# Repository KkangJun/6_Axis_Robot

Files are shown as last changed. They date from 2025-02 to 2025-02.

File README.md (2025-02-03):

Start : 2024. 12. 18
====================
v1.0 End : 2025. 02. 03
======================
   
## Introduction
 This project is a compilation of documents that I developed for my 6-axis manipulator robot.   
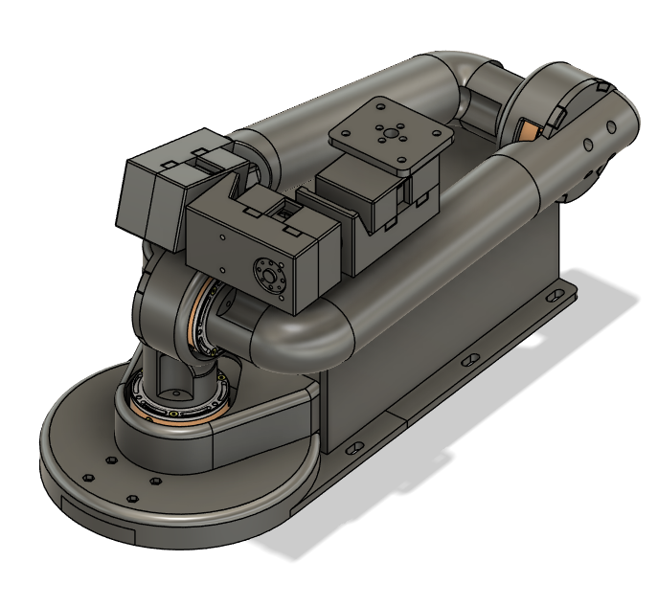
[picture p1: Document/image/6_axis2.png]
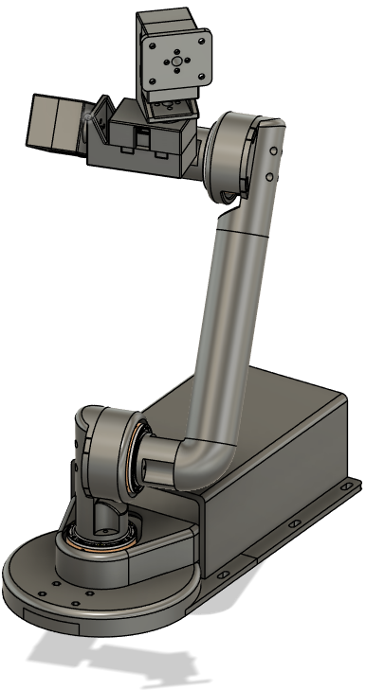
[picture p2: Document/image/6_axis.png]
<br/> <br/>
   
### Ver 1.0 Implement
 #### - Initialize -
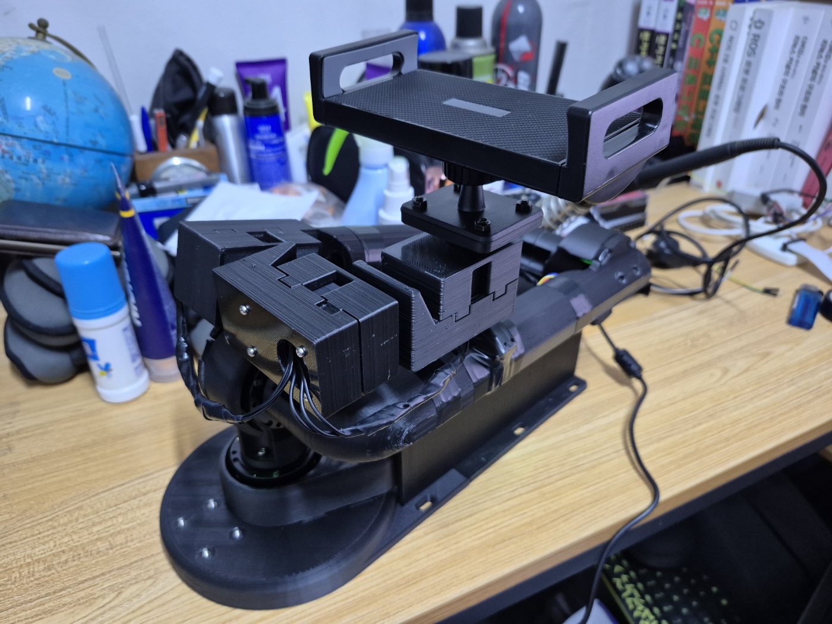
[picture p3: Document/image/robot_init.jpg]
<br/><br/>

 ##### The robot is initialized in the following cases:   
1. Power on the robot
2. Connect the App to the robot
3. Press the Reset button on the App
   
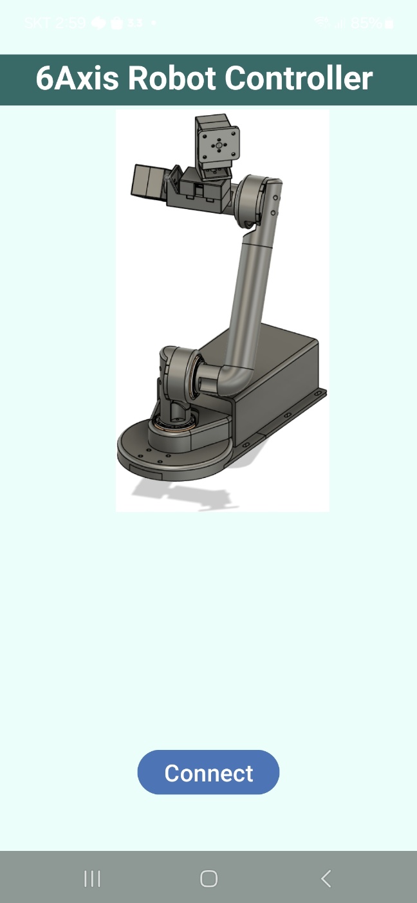
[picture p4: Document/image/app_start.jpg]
<br/><br/>
   
 #### - Motor control -
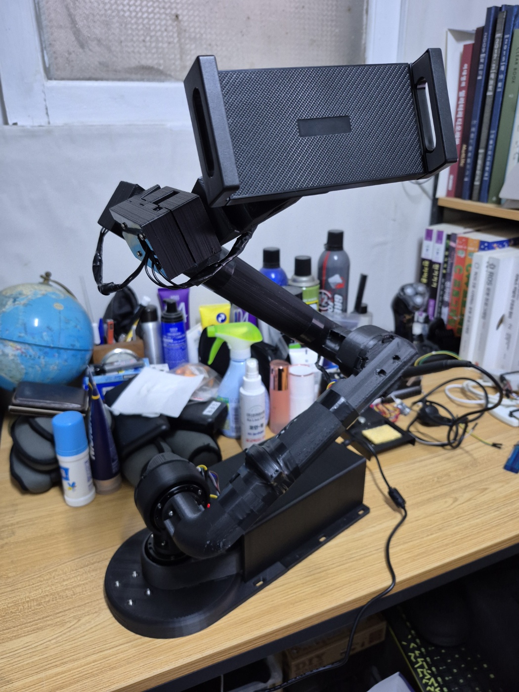
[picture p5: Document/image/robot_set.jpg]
<br/><br/>

 ##### To control each joint of the robot, we use the following methods:   
1. Set the motor angle by sliding or typing numbers
2. Press the RUN button to operate the motor according to the set angle value
3. Adjust the angle in the RUN state to operate the motor
   
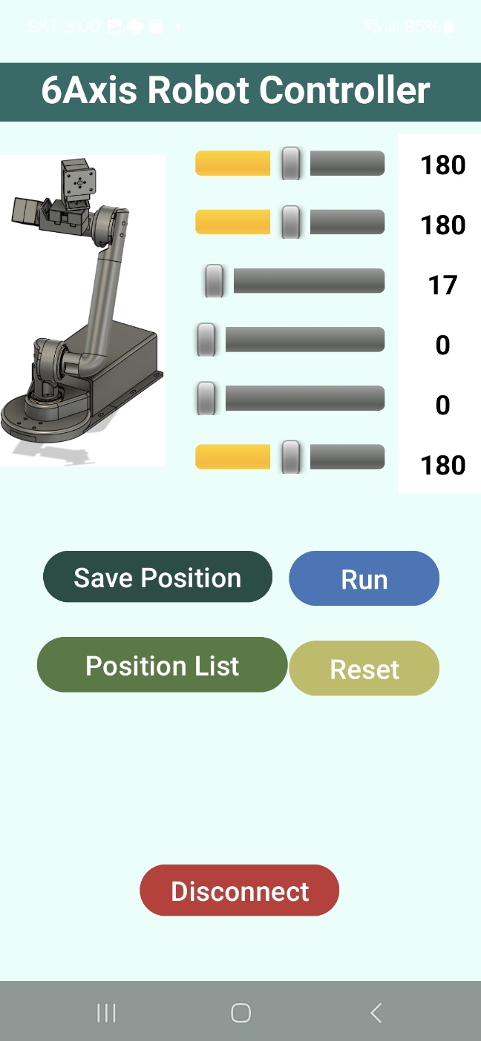
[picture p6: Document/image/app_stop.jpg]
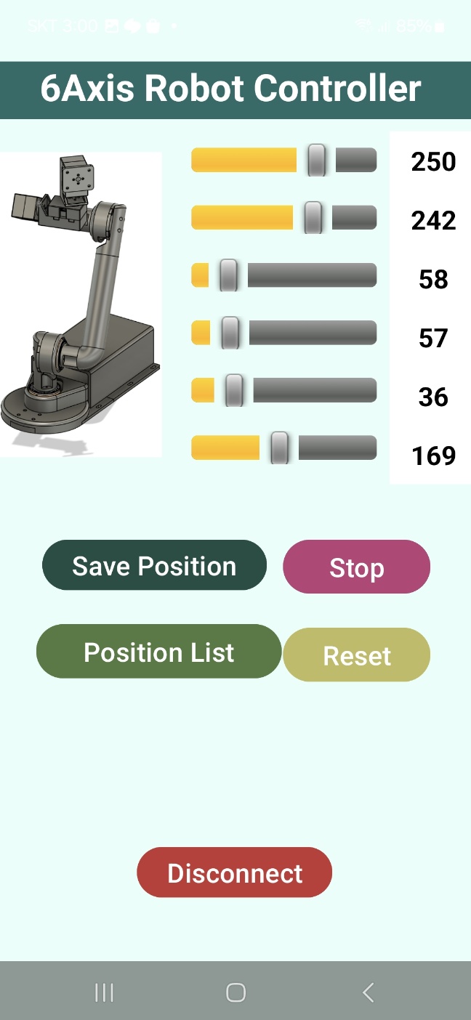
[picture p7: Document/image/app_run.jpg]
<br/> <br/>
   
 #### - Save motor position -
 ##### To save the robot's position, use the following method:   
1. Set the desired motor angle in the App and click the Save position button
2. Enter a name and click Save
   
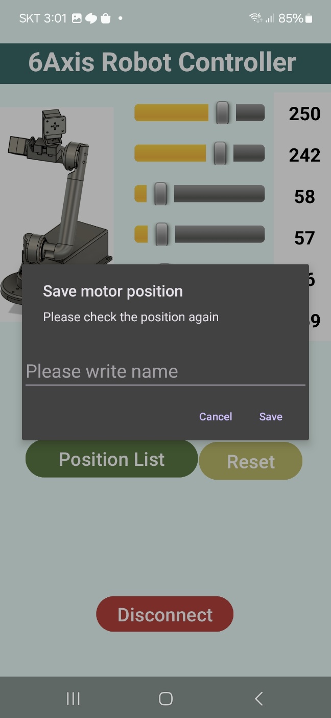
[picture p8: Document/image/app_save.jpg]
<br/><br/>
   
 #### - Load motor position -
 ##### To load the robot's position, use the following method:   
1. Click the Position list button
2. Click one of the saved positions and click the Set button
   
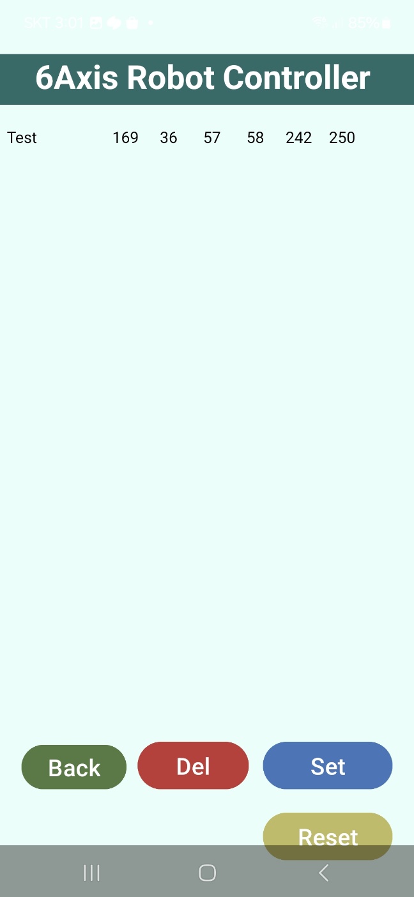
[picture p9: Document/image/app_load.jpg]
<br/><br/>
   
 #### - Voice Commands -
 ##### To control the robot's position with voice commands, use the following method:   
1. Start of voice command is "Hello robot"
2. Each custom command operates according to the saved position
3. "Reset" command to initialize the robot
   
## Reference
 For detailed development information, please refer to the Excel file in the document folder.   
 [Dev Doc](./Document/6_Axis_Robot.xlsx)   
    
 Thank you.

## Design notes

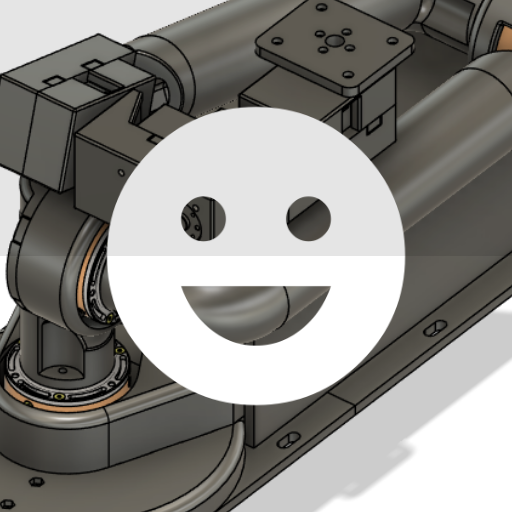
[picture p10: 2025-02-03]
design/android/play_store_512.png

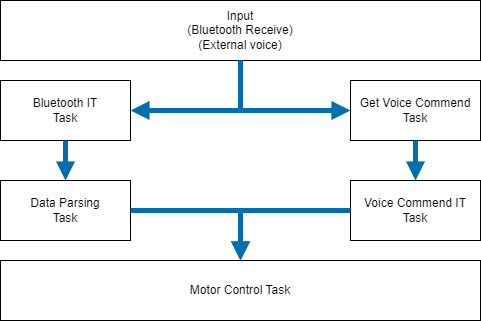
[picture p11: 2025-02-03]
design/Diagram/6_Axis_Architecture.png

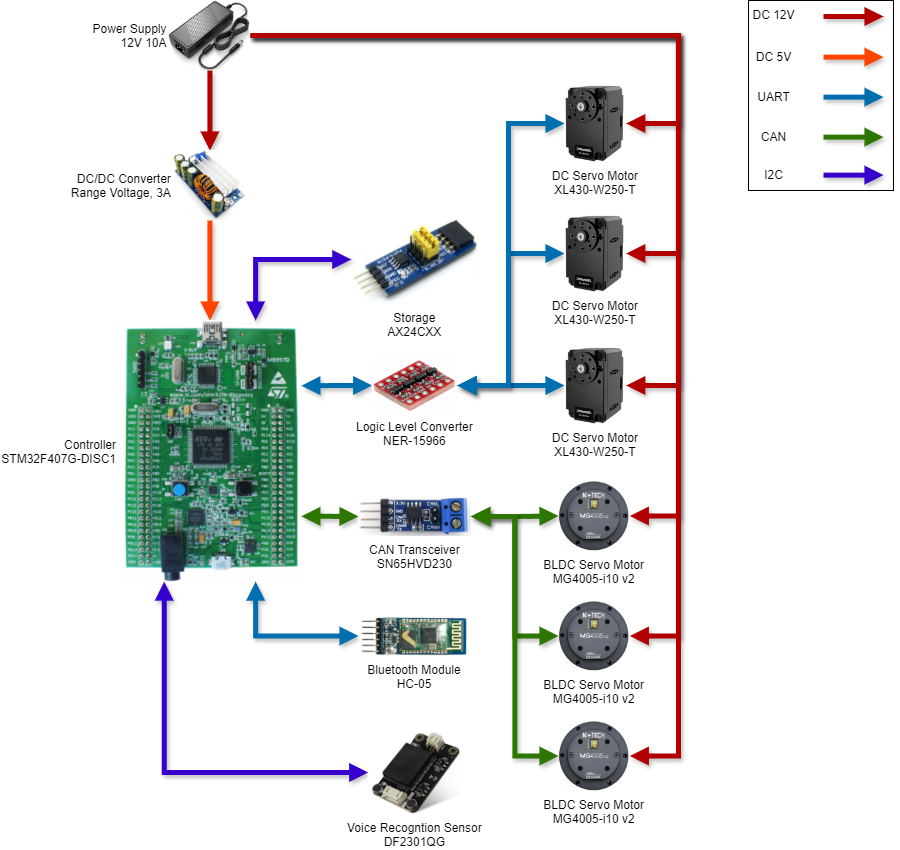
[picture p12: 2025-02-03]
design/Diagram/6_Axis_Diagram.png

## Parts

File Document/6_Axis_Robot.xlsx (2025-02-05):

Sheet: Schedule
Development Schedule
 |  |  |  |  |  |  |  |  |  |  |  |  |  |  |  |  |  |  |  |  |  |  |  |  |  |  |  |  | 계획 :
 |  |  |  |  |  |  |  |  |  |  |  |  |  |  |  |  |  |  |  |  |  |  |  |  |  |  |  |  | 실제 :
 | 1 | 2 | 3 | 4 | 5 | 6 | 7 | 8 | 9 | 10 | 11 | 12 | 13 | 14 | 15 | 16 | 17 | 18 | 19 | 20 | 21 | 22 | 23 | 24 | 25 | 26 | 27 | 28 | 29 | 30 | 31
2024.12
 |  |  |  |  |  |  |  |  |  |  |  |  |  |  |  |  |  |  |  |  |  |  |  |  |  |  |  |  |  |  | 병
2025.1
 |  | 병 | 병 | 병 | 병
2025.2
일지 |  |  |  |  |  |  |  |  |  |  |  |  |  |  |  |  |  |  |  |  |  |  |  |  |  |  |  |  |  |  |  | Note.
2024. 12. 18 |  | 6축 로봇 구상. 모터 선정. 그 외 통신에 필요한 모듈 선정. |  |  |  |  |  |  |  |  |  |  |  |  |  |  |  |  |  |  |  |  |  |  |  |  |  |  |  |  |  | 모터 구매 이슈. 발주 후 약 2주 소요 예정이라 선 구매
2024. 12. 19 |  | 전원 공급기, 컨버터 등 필요 물품 선정 및 구매. BOM 작성. Diagram 작성.
2024. 12. 20 |  | HIS 작성, 회로도 작성.
2024. 12. 23 |  | 3D 모델링 (베이스, 제어함 부분).
2024. 12. 24 |  | 3D 모델링 (로봇 암 부분), 대체 모터 선정 및 구매. |  |  |  |  |  |  |  |  |  |  |  |  |  |  |  |  |  |  |  |  |  |  |  |  |  |  |  |  |  | AX-12A 모터 설계상 문제로 인한 모터 3개 교체 (XL-430W250-T)
2024. 12. 25 |  | 추가 부품 구매. Diagram, 회로도 수정. 3D 모델링 (로봇 암 부분). |  |  |  |  |  |  |  |  |  |  |  |  |  |  |  |  |  |  |  |  |  |  |  |  |  |  |  |  |  | 모터 2종류 (총 6개) 발송 지연 => 1월 중순 배송예정
2024. 12. 27 |  | 3D 모델링 (베이스, 제어함 부분 수정 -> 3D 프린터 사이즈에 맞추기 위해 조립식으로 변경).
2024. 12. 30 |  | 6축 로봇 제어 APP 개발. |  |  |  |  |  |  |  |  |  |  |  |  |  |  |  |  |  |  |  |  |  |  |  |  |  |  |  |  |  | 12. 31 ~ 1. 5 독감으로 인해 휴식
2025. 01. 01 |  | 6축 로봇 제어 APP 개발 (블루투스 제외 프로토타입 개발 완료).
2025. 01. 06 |  | HC-05 블루투스 모듈 작동 Test (PC <-> MCU <-> HC-05 <-> Phone).
2025. 01. 07 |  | 조립 및 테스트에 필요한 자재 추가 구매, 6축 로봇 제어 APP 개발 (블루투스 연결, 데이터 송신 구현 완료).
2025. 01. 08 |  | 소프트웨어 아키텍처 작성.
2025. 01. 09 |  | 모터 Testbed 제작. MG4005 통신 프로토콜 분석, 모터 세팅 |  |  |  |  |  |  |  |  |  |  |  |  |  |  |  |  |  |  |  |  |  |  |  |  |  |  |  |  |  | MG4005 모터 세팅 이슈.
2025. 01. 11 |  | MG4005 CAN 제어, 위치 제어 테스트
2025. 01. 13 |  | MG4005 CAN 제어, 위치 제어 테스트
2025. 01. 14 |  | XL430 통신 프로토콜 분석, 모터 세팅, 테스트
2025. 01. 15 |  | XL430 모터 세팅, Serial 제어, 위치 제어 테스트 |  |  |  |  |  |  |  |  |  |  |  |  |  |  |  |  |  |  |  |  |  |  |  |  |  |  |  |  |  | XL430 모터 통신 이슈.
2025. 01. 17 |  | 설계에 저장장치(EEPROM)추가. 음성 인식 센서, 저장장치 Test
2025. 01. 21 |  | APP <-> 로봇 간 데이터 form 설정, FreeRTOS Task 설정
2025. 01. 22 |  | 3D 프린터물 검수 (유격 오차 가공 및 가조립)
2025. 01. 23 |  | 데이터 입출력, 데이터 파싱 Task 코딩
2025. 01. 24 |  | 데이터 입력, 파싱, Task 작동 테스트 |  |  |  |  |  |  |  |  |  |  |  |  |  |  |  |  |  |  |  |  |  |  |  |  |  |  |  |  |  | Voice sensor 데이터 Read 이슈.
2025. 01. 25 |  | APP <-> 로봇 간 데이터 form 수정, 6축 로봇 제어 APP 수정 (데이터, 버튼 시퀀스 등)
2025. 01. 28 |  | 조립 전 모터 작동 및 방향 테스트, 6축 로봇 하드웨어 제작 (조립 70%, 배선 80%) |  |  |  |  |  |  |  |  |  |  |  |  |  |  |  |  |  |  |  |  |  |  |  |  |  |  |  |  |  | XL430 모터 통신 이슈, FreeRTOS Hard fault 이슈.
2025. 01. 29 |  | 6축 로봇 제작 중간 모터 구동 테스트
2025. 01. 30 |  | 6축 로봇 하드웨어 제작 완료. 작동 테스트 |  |  |  |  |  |  |  |  |  |  |  |  |  |  |  |  |  |  |  |  |  |  |  |  |  |  |  |  |  | 모터 토크 이슈
2025. 01. 31 |  | EEPROM 회로 변경, 6축 로봇 프로토타입 작동 테스트 완료
2025. 02. 03 |  | 문서 수정 및 추가 작성 (회로도 수정, HIS 수정, 프로토콜 작성)

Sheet: Diagram
Diagram
 | Note.
 | 2024-12-25 모터 변경 및 음성 센서 추가
 | 2025-01-17 EEPROM 추가

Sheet: Electric Circuit
Electric Circuit
 | Note.
 | 2024-12-25 모터 변경 및 음성 센서 추가
 | 2025-01-15 MCU usart 핀 변경 (보드 회로 문제 -> 사용하려던 핀이 이미 보드에 포함된 다른 장치에 연결되어있음)
 | 2025-01-17 EEPROM 추가
 | 2025-02-03 EEPROM 회로 수정

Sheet: Interface
Hardware & Software Interface
PORT | Pin name | ADD Func | ALT Func1 | ALT Func2 | ALT Func3 | ALT Func4 | ALT Func5 | ALT Func6 | ALT Func7 | ALT Func8 | ALT Func9 | ALT Func10 | ALT Func11 | ALT Func12 | ALT Func13 | Used Pin
PortA | PA2 |  | TIM2_CH3 | TIM5_CH3 | TIM9_CH1 |  |  |  | USART2_TX |  |  |  | ETH_MDIO |  |  | USART2_TX
 | PA3 |  | TIM2_CH4 | TIM5_CH4 | TIM9_CH2 |  |  |  | USART2_RX |  |  | OTG_HS_ULPI_ D0 | ETH _MII_COL |  |  | USART2_RX
PortB | PB7 |  |  | TIM4_CH2 |  | I2C1_SDA |  |  | USART1_RX |  |  |  |  | FSMC_N | DCMI_VSYNC | I2C1_SDA
 | PB8 |  |  | TIM4_CH3 | TIM10_CH1 | I2C1_SCL |  |  |  |  | CAN1_RX |  | ETH _MII_TXD3 | SDIO_D4 | DCMI_D6 | I2C1_SCL
 | PB10 |  | TIM2_CH3 |  |  | I2C2_SCL | SPI2_SCK I2S2_CK |  | USART3_TX |  |  | OTG_HS_ULPI_ D3 | ETH_ MII_RX_ER |  |  | USART3_TX (Half duplex)
 | PB12 |  | TIM1_BKIN |  |  | I2C2_SMBA | SPI2_NSS I2S2_WS |  | USART3_CK |  | CAN2_RX | OTG_HS_ULPI_ D5 | ETH _MII_TXD0 ETH _RMII_TXD0 | OTG_HS_ID |  | CAN2_RX
 | PB13 |  | TIM1_CH1N |  |  |  | SPI2_SCK I2S2_CK |  | USART3_CTS |  | CAN2_TX | OTG_HS_ULPI_ D6 | ETH _MII_TXD1 ETH _RMII_TXD1 |  |  | CAN2_TX
PortD | PD12 |  |  | TIM4_CH1 |  |  |  |  | USART3_RTS |  |  |  |  | FSMC_A17 |  | GPIO Output
 | PD13 |  |  | TIM4_CH2 |  |  |  |  |  |  |  |  |  | FSMC_A18 |  | GPIO Output
 | PD14 |  |  | TIM4_CH3 |  |  |  |  |  |  |  |  |  | FSMC_D0 |  | GPIO Output
 | PD15 |  |  | TIM4_CH4 |  |  |  |  |  |  |  |  |  | FSMC_D1 |  | GPIO Output
PortH | PH0 | OSC_IN |  |  |  |  |  |  |  |  |  |  |  |  |  | OSC_IN
 | PH1 | OSC_OUT |  |  |  |  |  |  |  |  |  |  |  |  |  | OSC_OUT
 |  |  |  |  |  |  |  |  |  |  |  |  |  |  |  |  | Note.
 |  |  |  |  |  |  |  |  |  |  |  |  |  |  |  |  | 2025-01-15 MCU usart 핀 변경 (보드 회로 문제 -> 사용하려던 핀이 이미 보드에 포함된 다른 장치에 연결되어있음)
Protocol |  |  |  |  |  |  |  |  |  |  |  |  |  |  |  |  | 2025-01-17 EEPROM 관련 핀 추가
 |  |  |  |  |  |  |  |  |  |  |  |  |  |  |  |  | 2025-02-03 EEPROM 관련 핀 삭제 (I2C1로 통합)
Bluetooth data form
Data name |  | Data Type | Data format |  |  | Value range
BLE Connect |  | String | CON\r\n
BLE Disconnect |  | String | DCON\r\n
App Distroy |  | String | DIS\r\n
Motor angle set |  | String | SET.$pos1.$pos2.$pos3.$pos4.$pos5.$pos6\r\n |  |  |  | pos1 = 0 ~ 360 | pos2 = 0 ~ 184 | pos3 = 0 ~ 332 | pos4 = 0 ~ 360 | pos5 = 0 ~ 360 | pos6 = 0 ~ 360
Motor Stop |  | String | STOP\r\n
Save position |  | String | SAV.$idx.$pos1.$pos2.$pos3.$pos4.$pos5.$pos6\r\n |  |  | idx = 0 ~ 4 | pos1 = 0 ~ 360 | pos2 = 0 ~ 184 | pos3 = 0 ~ 332 | pos4 = 0 ~ 360 | pos5 = 0 ~ 360 | pos6 = 0 ~ 360
Delete position |  | String | DEL.&idx |  |  | idx = 0 ~ 4
Motor ID
Data form name |  | Motor name | ID
pos1 |  | MG4005 | 0x01
pos2 |  | MG4005 | 0x02
pos3 |  | MG4005 | 0x03
pos4 |  | XL430 | 0x04
pos5 |  | XL430 | 0x05
pos6 |  | XL430 | 0x06
Voice Sensor Commend
Commend |  |  | Value
Hello robot |  |  | 0x02
Costom cmd 1 (Load Position 1) |  |  | 0x05
Costom cmd 2 (Load Position 2) |  |  | 0x06
Costom cmd 3 (Load Position 3) |  |  | 0x07
Costom cmd 4 (Load Position 4) |  |  | 0x08
Costom cmd 5 (Load Position 5) |  |  | 0x09
Costom cmd 6 (Guidance voice ON) |  |  | 0x0A
Costom cmd 7 (Guidance voice OFF) |  |  | 0x0B
Reset |  |  | 0x52

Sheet: SW Architecture
Software Architecture
 |  |  | Note.
 |  |  | 2025-01-17 EEPROM 부분 추가
 |  |  | 2025-02-03 Task로 분리
Task name | synchronous | Task Cycle (ms)
Bluetooth IT | Async | Semaphore
Get Voice | Async | 100
Data Parsing | Async | 1
Voice IT | Async | Semaphore
Motor Control | Async | 1

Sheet: Function definition
Function definition

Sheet: BOM
 | Bill of Materials
 | 품목 | 품목명 | 수량 | 단위 | 단가 | 금액 | 구매처 | 비고
 | Power Supply | DC12V 10A 어댑터 (연장 탈피 케이블, 전원선) | 1 | EA | ₩25500 | ₩25500 | Link (https://smartstore.naver.com/mhe/products/4957502930?n_media=11068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)
 | DC Converter | XL6009 Buck-Boost DC-DC 듀얼 컨버터 모듈 | 1 | EA | ₩5500 | ₩5500 | Link (https://smartstore.naver.com/devicemart_official/products/9668994234?nl-au=fb3f918f43d541f1bc421ed4006740f1)
 | Controller | STM32F407G-DISC1 | 1 | EA | ₩39000 | ₩39000 | Link (https://www.devicemart.co.kr/goods/view?no=1377153&market=naver) | 재고
 | Motor | MG4005-i10 v2 (CAN-18bit) | 3 | EA | ₩185600 | ₩556800 | Link (https://smartstore.naver.com/shinanglobal20/products/10265269410) | 해외 배송
 | Motor | Dynamixel XL430-W250-T | 3 | EA | ₩52800 | ₩158400 | Link (https://smartstore.naver.com/devicemart_official/products/10493342027)
 | Motor Accessory | HN11-I101 Set | 3 | SET | ₩8470 | ₩25410 | Link (https://www.robotis.com/shop/item.php?it_id=903-0265-000)
 | Signal Converter | SN65HVD230 CAN통신 트랜시버 | 1 | EA | ₩9900 | ₩9900 | Link (https://smartstore.naver.com/devicemart_official/products/10321506035?nl-au=70fcaa997b604b858a04f0d2ff51d261)
 | Signal Converter | 4CH Logic Level Converter (NER-15966) | 1 | EA | ₩3960 | ₩3960 | Link (https://smartstore.naver.com/devicemart_official/products/10239056100?nl-au=fb5d67c45fa349bb80e5dc6027d5ff71)
 | Electrical Parts | 핀헤더 Single 스트레이트 타입 DIP 2.54mm 20핀 | 1 | EA | ₩80 | ₩80 | Link (https://smartstore.naver.com/devicemart_official/products/9463684329?nl-au=c943bcd740dd4a1f8227b158e09922e7)
 | Electrical Parts | 120옴 저항 1/2W 5% (100개) | 1 | SET | ₩1600 | ₩1600 | Link (https://www.icbanq.com/paymentorder/basket.do)
 | Module | HC-05 Bluetooth module | 1 | EA | ₩6600 | ₩6600 | Link (https://smartstore.naver.com/devicemart_official/products/9525225880) | 재고
 | Sensor | Voice Recogntion Sensor SEN0539 (DF2301QG) | 1 | EA | ₩22000 | ₩22000 | Link (https://www.icbanq.com/P015403098)
 | Storage | AX24CXX (EEPROM) | 1 | EA | ₩5400 | ₩5400 | Link (https://www.eleparts.co.kr/goods/view?no=436527) | 재고
 | ETC | 17mm 볼 헤드 마운트 (AMPS 규격) | 1 | EA | ₩6300 | ₩6300 | Link (https://brand.naver.com/arkonkorea/products/6747462300)
 | ETC | 태블릿 거치대 헤드 SD-20 | 1 | EA | ₩4900 | ₩4900 | Link (https://smartstore.naver.com/tabletmarket/products/10244541861)
 | Cable | 10색 절연전선 1M | 5 | EA | ₩1300 | ₩6500 | Link (https://www.devicemart.co.kr/goods/view?no=24944)
 | Bolt | M2x15 | 4 | EA | ₩200 | ₩800 | Link (https://www.devicemart.co.kr/goods/view?no=10915161)
 | Bolt | M2x12 | 8 | EA | ₩200 | ₩1600 | Link (https://www.devicemart.co.kr/goods/view?no=10915160)
 | Bolt | M2.5x15 | 4 | EA | ₩90 | ₩360 | Link (https://www.devicemart.co.kr/goods/view?no=10915168)
 | Bolt | M2.5x12 | 4 | EA | ₩90 | ₩360 | Link (https://www.devicemart.co.kr/goods/view?no=10915167)
i | Bolt | M2.5x8 | 8 | EA | ₩70 | ₩560 | Link (https://www.devicemart.co.kr/goods/view?no=10915165)
 | Bolt | M2.5x6 | 12 | EA | ₩70 | ₩840 | Link (https://www.devicemart.co.kr/goods/view?no=10915164)
 | Bolt | M3x20 | 4 | EA | ₩60 | ₩240 | Link (https://www.devicemart.co.kr/goods/view?no=34536)
 | Bolt | M3x15 | 4 | EA | ₩40 | ₩160 | Link (https://www.devicemart.co.kr/goods/view?no=10912492)
 | Bolt | M3x8 | 9 | EA | ₩40 | ₩360 | Link (https://www.devicemart.co.kr/goods/view?no=10912489)
 | Nut | M3 | 12 | EA | ₩70 | ₩840 | Link (https://www.devicemart.co.kr/goods/view?no=10893596)
 |  |  |  |  |  | ₩0
 |  |  |  |  | Total | ₩883970

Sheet: Trouble Shooting
Trouble Shooting
발생일자 | 문제점 | 해결 방안 | 완료일자 | 원인 | 비고
2025. 1. 6 | HC-05 모듈의 baud rate을 HC-05 데이터시트와 일치(38400) 시켰음에도 통신이 불량인 상황. | 칩 자체의 데이터시트가 아닌 HC-05 모듈 판매처에서 baud rate 확인. | 2025. 1. 6 | HC-05를 사용한 블루투스 모듈 제품은 baud rate이 9600으로 설정되어 출고 되고 있었음.
2025. 1. 9 | MG4005 모터 제조사에서 제공하는 프로그램으로 엔코더값을 이용한 영점을 세팅해도 전원을 토글하면 영점대로 작동하지 않음. | 제공하는 프로그램의 테스트 코드가 실제 사용할 CAN 프로토콜과 다를 수 있으므로, MCU에서 직접 CAN 통신 제어 시도. | 2025. 1. 13 | 모터에 장착된 엔코더가 Single ring 타입이고 1:10 감속기 적용 후 위치가 아닌 감속기 축 쪽에 장착되있는 것으로 예상. 그로인해 엔코더 값이 0~360도가 아닌 36도 마다 맵핑 되어있음. | 로봇의 전원 On/Off 전후로 엔코더 영점값이 실제 포함되어있는 각도(36도) 사이에 위치하도록 영점 위치 제어 필요. 추후에는 Single turn 타입 구매를 권장.
2025. 1. 15 | XL430 모터 <-> MCU 통신 불가. | MCU의 Uart Peripheral이 Half Duplex를 지원하는지 확인 필요. 통신 회로 분석(보드 회로 포함). | 2025. 1. 15 | 사용하려는 Pin이 이미 타깃 보드에 포함된 다른 장치 회로와 연결되어있어서 정상작동이 불가능 했음.
2025. 1. 24 | APP, Voice Sensor <-> MCU 테스트 중, Voice Sensor 통신 불가. Voice Sensor의 커맨드 값을 읽어오는동안 Timeout Error 발생. | 인터럽트 우선순위 변경, 통신하는 동안 Delay 조정 | 2025. 1. 24 | Voice Sensor의 전력 문제로 인한 통신 에러. 조립 전 테스트 중이라, 타겟보드의 외부 전원을 사용. 전원 포트가 적어 블루투스 모듈과 같이 연결한 것이 문제. | 센서 모듈의 다른 기능은 작동을 잘 했지만, 통신에 있어서 충분한 전력공급이 필요하다는 것을 인지
2025. 1. 28 | 조립전 확인을 위해 모터 작동 테스트를 하였으나, XL430 모터 다중 제어 시 작동 이상. | 통신 딜레이 증가, Baud rate 변경 | 2025. 1. 28 | 이전과 다른 부분은 없었음에도, 어떠한 외부 요인(노이즈 등)에 의해 통신 타이밍이 안맞은 것 같음. 모터에서 데이터 처리하는 것을 기다리기 위해 딜레이 증가, Baud rate 변경
2025. 1. 28 | FreeRTOS Motor Task에서 Hard fault 에러. | 스택 사이즈 증가 | 2025. 1. 28 | 모터제어와 관련되어 처리할 데이터 양이 예상보다 많았음
2025. 1. 30 | 설계시 토크를 계산한 것보다 모터가 부하를 더 받음. (100% 동작 불가) | 바디 프레임(3D 프린트물) 경량화, 모터 변경 필요 (높은 토크값) | 2025. 1. 30 | 바디 프레임의 무게를 실제보다 가볍게 생각하고 설계. | 3D 프린트물이 기본적으로 단단하긴 하나 열에 매우 취약.

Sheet: Dev Tool
Develop Tool
사용 목적 | Tool 명 | Version
Diagram | draw.io | 25.0.2
Electric Circuit | Nano CAD 5 | 5.0.2547.1471
3D Modeling | Autodesk Fusion 360 | 2.0.20981
IDE (MCU) | STM32CubeIDE | 1.13.2
IDE (Android App) | Android Studio | 21.0.3

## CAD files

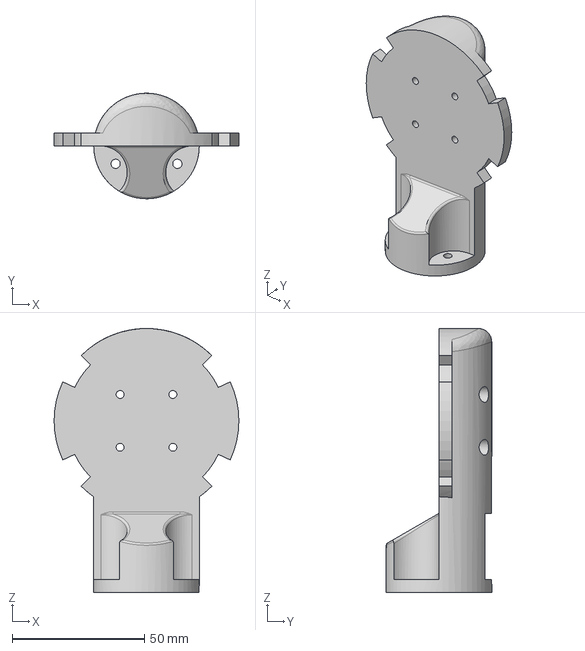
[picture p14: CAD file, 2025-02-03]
design/3D_Modeling/6_Axis_1arm.step
70.0 x 40.0 x 100.0 mm

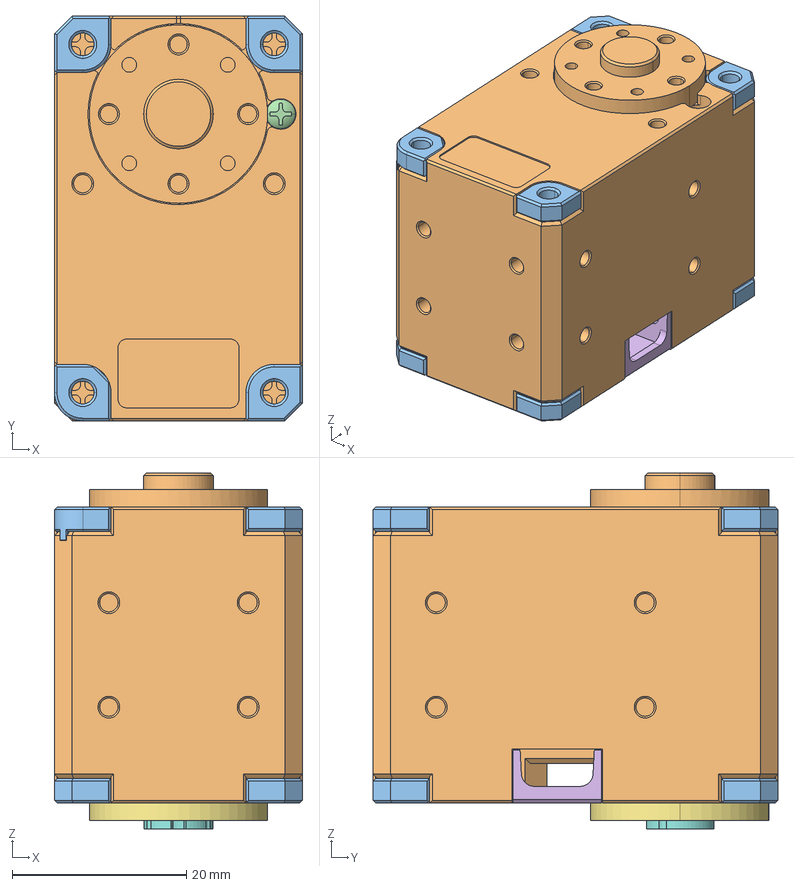
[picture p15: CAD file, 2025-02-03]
Reference/XL-430_new.stp
28.5 x 46.5 x 40.9 mm
DC11_A01_DUMMY
DX124_SCREW-COVER
B3B-EH x 2
DC11_A01_CASE_CVR_DUMMY
DC11_A01_IDLER_DUMMY
DC11_A01_IDLER_CAP_DUMMY
DC11_A01_IDLER_SCREW
FHS_M2_5X10 x 8
DC11_A01_SPACER_DUMMY x 8

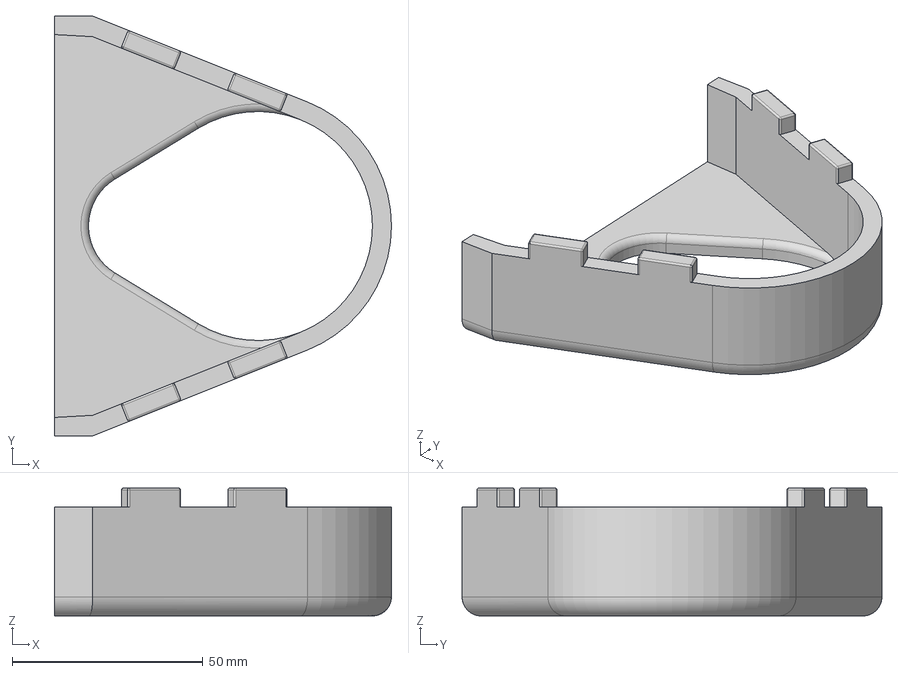
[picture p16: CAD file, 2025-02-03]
design/3D_Modeling/6_Axis_0base_1cover.step
88.3 x 110.0 x 33.5 mm

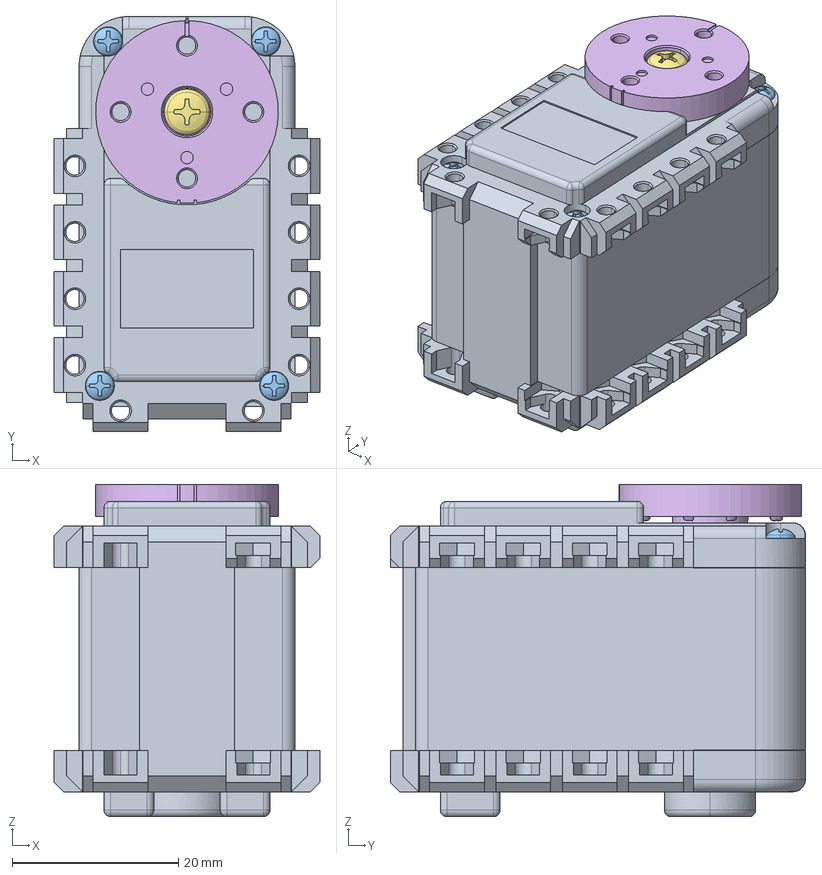
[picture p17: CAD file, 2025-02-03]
Reference/AX-12A.stp
32.0 x 50.0 x 40.0 mm
PRT0001
PRT0002
PRT0003 x 4
PRT0004 x 2
PRT0005
PRT0006
PRT0007

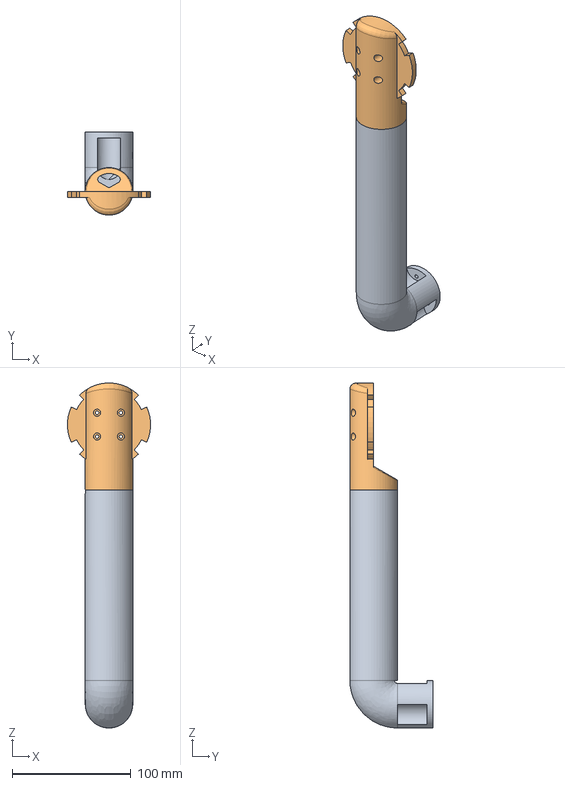
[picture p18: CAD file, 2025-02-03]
design/3D_Modeling/6_Axis_2arm.step
69.9 x 70.0 x 290.0 mm

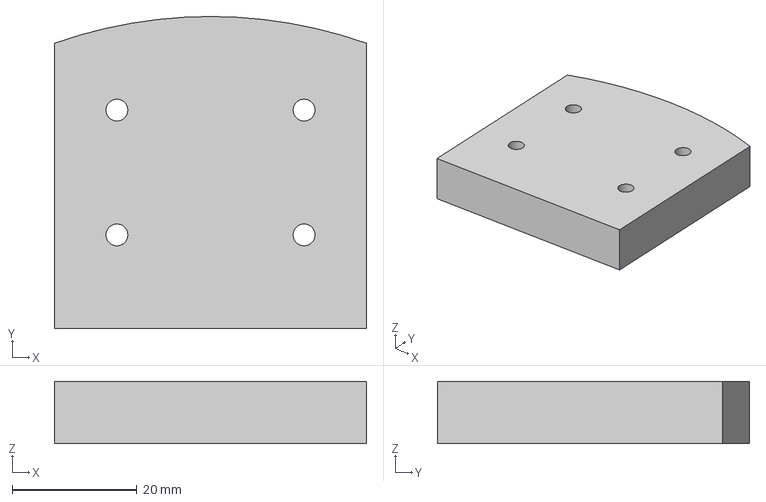
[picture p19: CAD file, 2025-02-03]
design/3D_Modeling/6_Axis_0base_0plate.step
50.0 x 50.0 x 10.0 mm

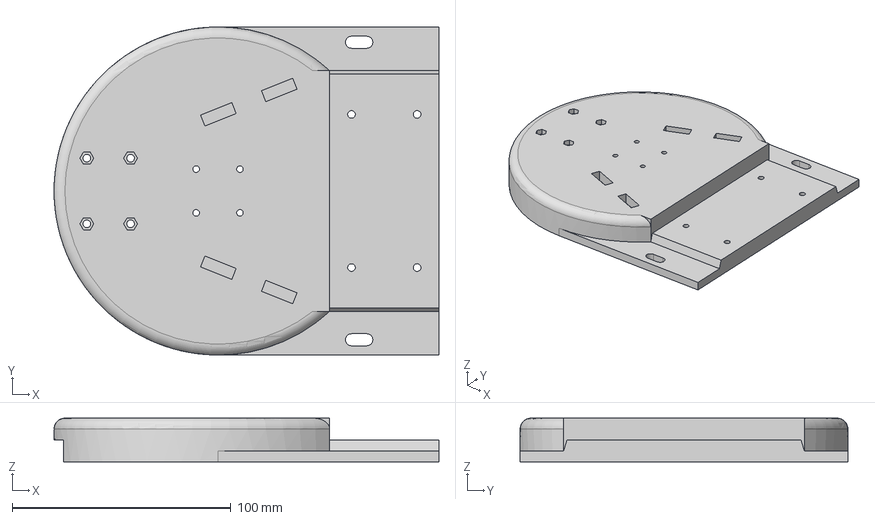
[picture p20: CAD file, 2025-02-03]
design/3D_Modeling/6_Axis_0base.step
176.0 x 150.0 x 20.0 mm

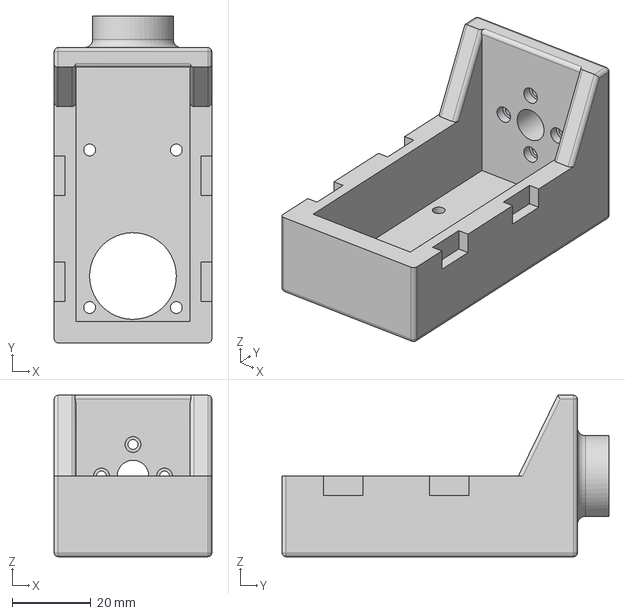
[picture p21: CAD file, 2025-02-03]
design/3D_Modeling/6_Axis_4_5arm.step
40.0 x 83.0 x 41.0 mm

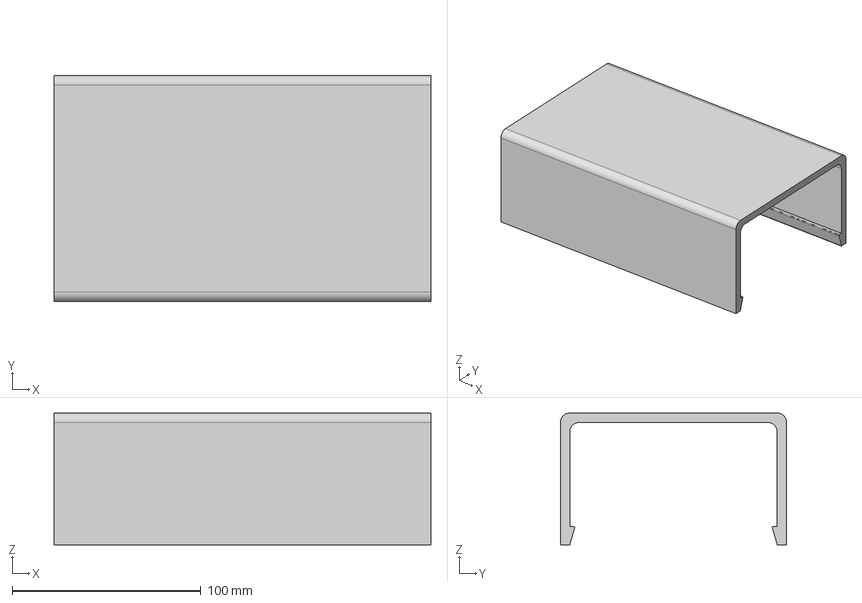
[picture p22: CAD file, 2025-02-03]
design/3D_Modeling/6_Axis_0base_0cover.step
200.0 x 120.0 x 70.0 mm

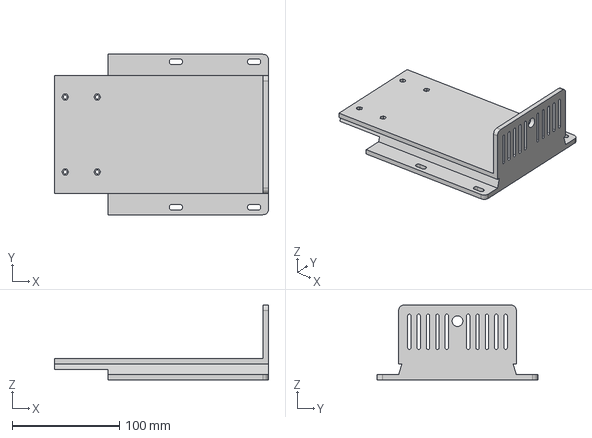
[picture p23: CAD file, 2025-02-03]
design/3D_Modeling/6_Axis_0base_controlbox.step
200.0 x 150.0 x 70.0 mm

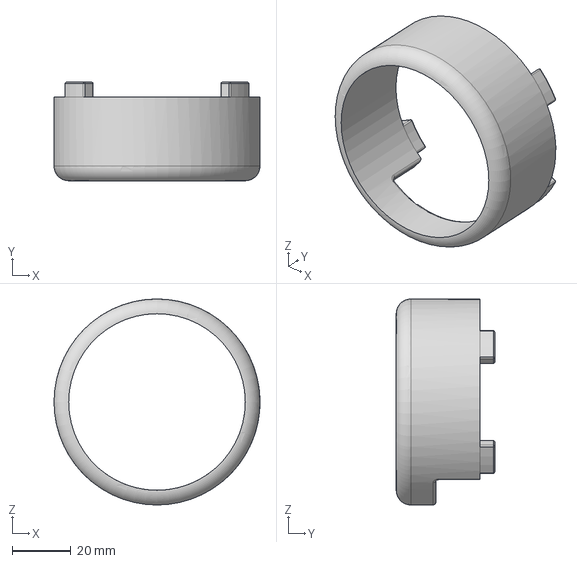
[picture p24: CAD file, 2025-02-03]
design/3D_Modeling/6_Axis_1_2arm_cover.step
70.0 x 33.5 x 70.0 mm

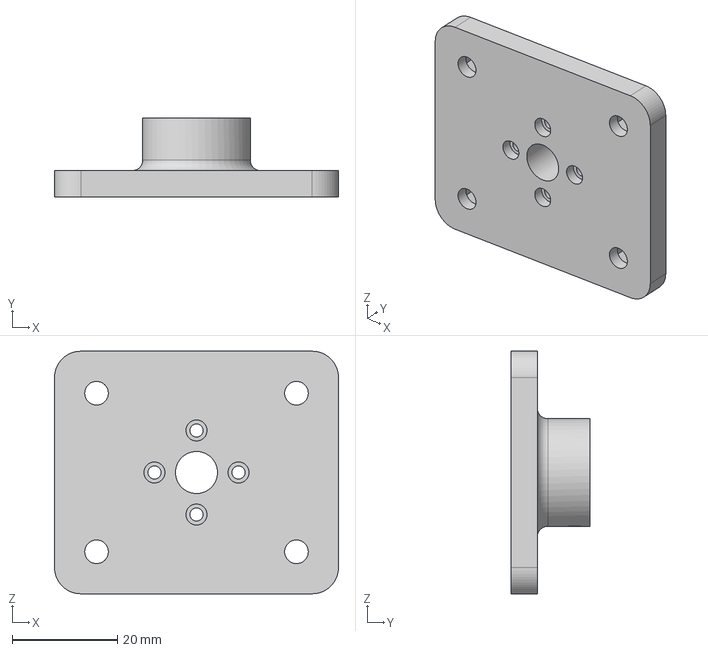
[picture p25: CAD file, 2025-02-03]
design/3D_Modeling/6_Axis_6stand_mount.step
54.0 x 15.0 x 46.2 mm

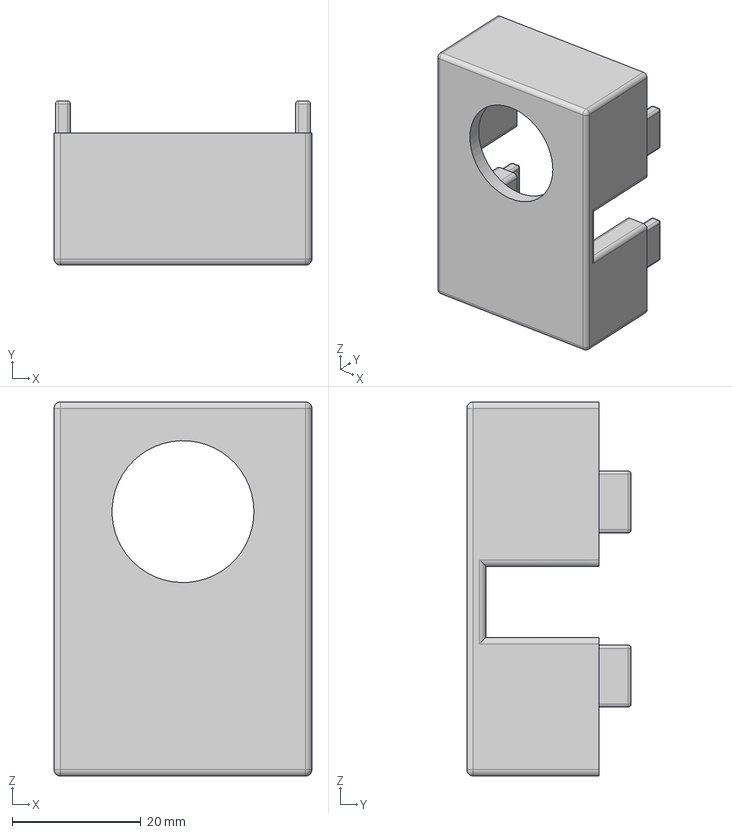
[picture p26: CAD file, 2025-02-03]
design/3D_Modeling/6_Axis_3_4_5arm_corver.step
40.0 x 25.5 x 58.0 mm

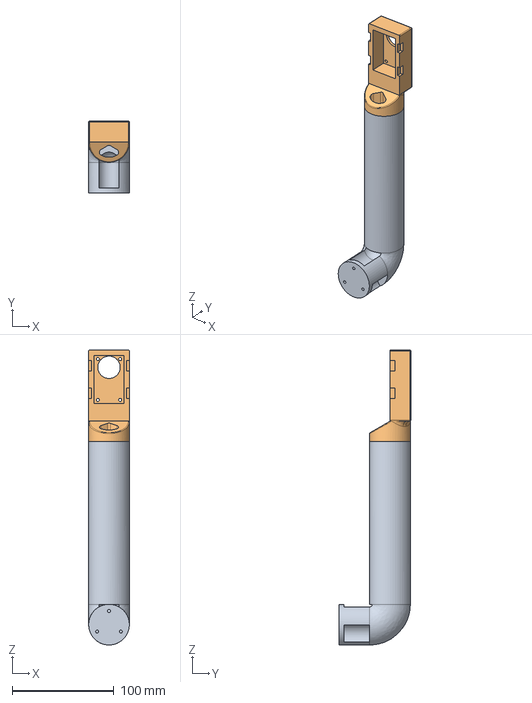
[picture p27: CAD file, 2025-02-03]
design/3D_Modeling/6_Axis_3arm.step
40.0 x 70.5 x 290.0 mm

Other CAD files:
design/Electic_Circuit/6_Axis_Electric_Circuit.dwg

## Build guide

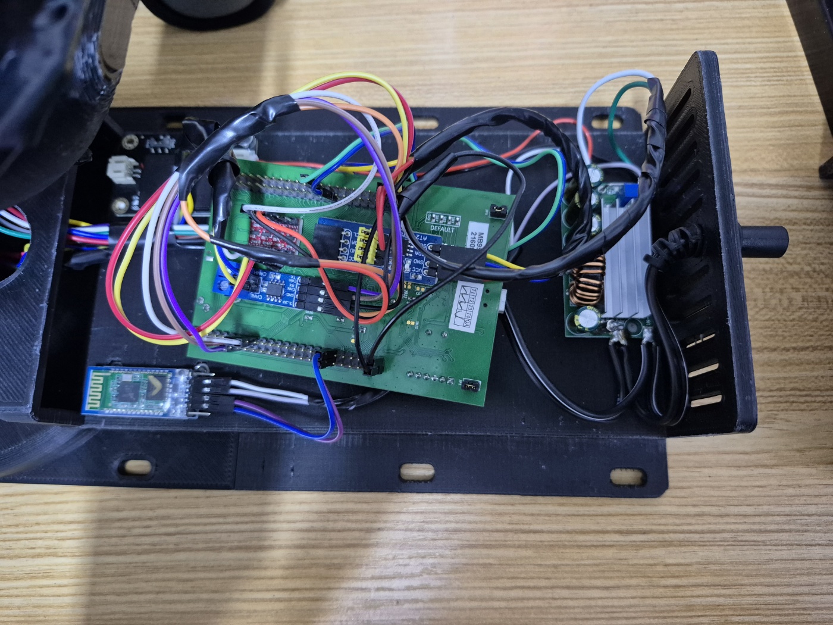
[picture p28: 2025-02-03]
Document/image/wiring.jpg

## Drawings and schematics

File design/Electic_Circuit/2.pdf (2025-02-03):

9

8

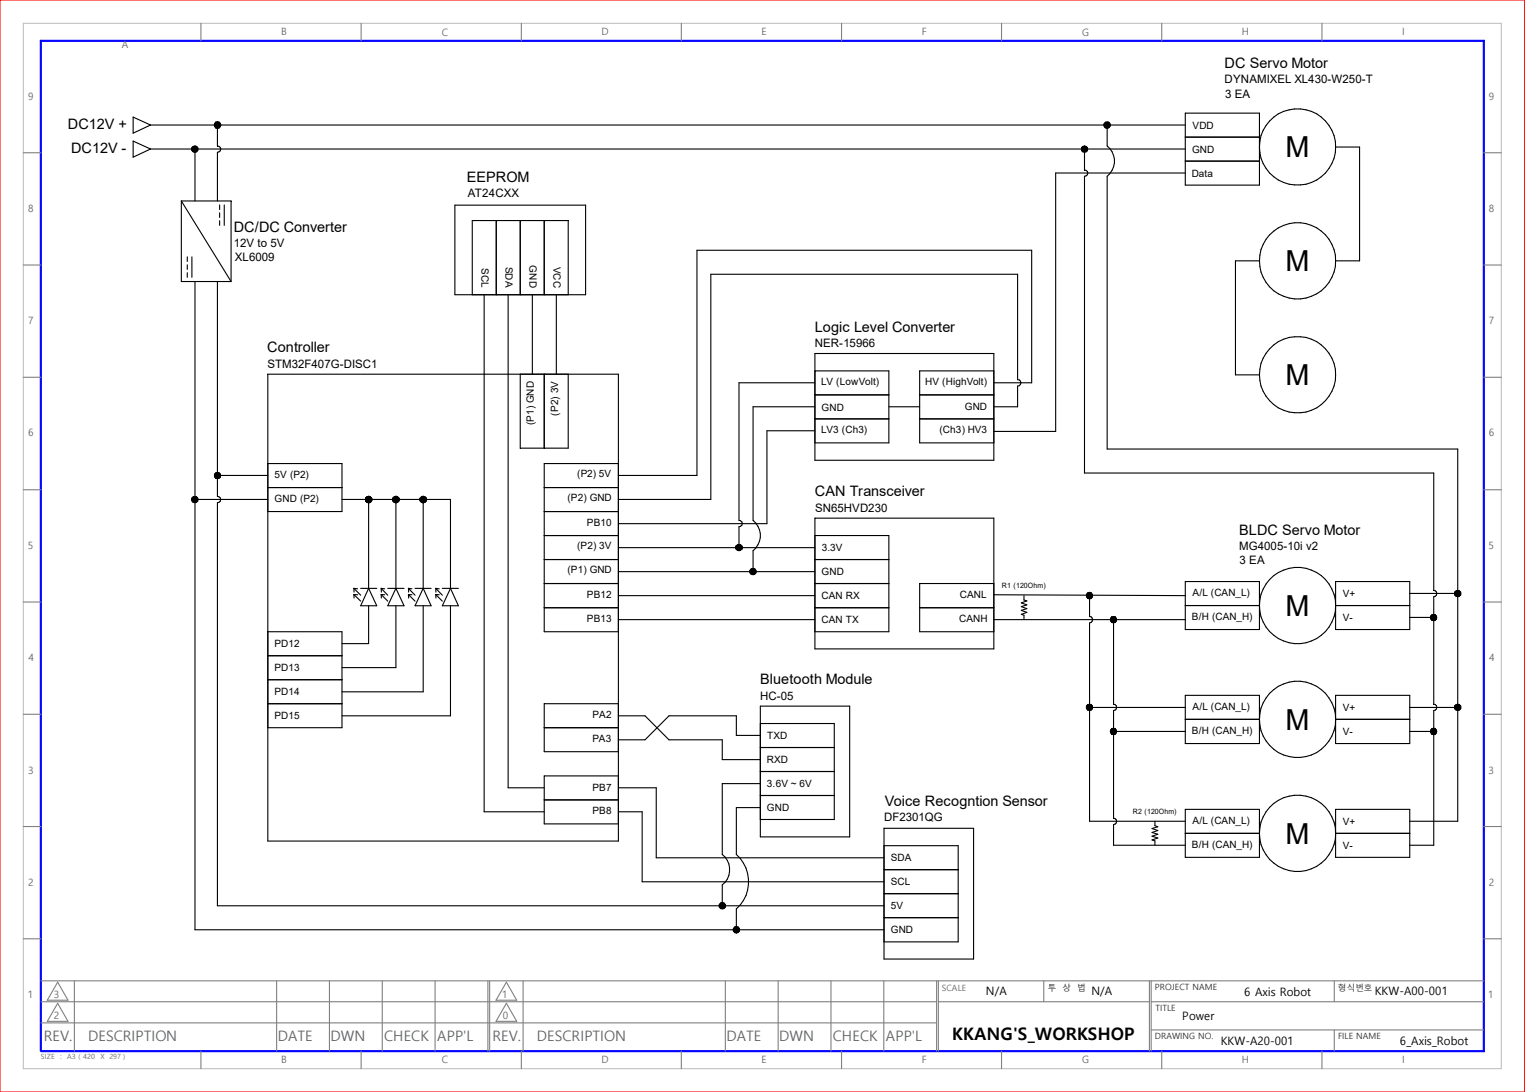
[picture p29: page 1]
SIZE : A3 ( 420 X 297 ); 0 REV.; DESCRIPTION; DATE; DWN; CHECK; APP'L; REV.; SCALE; KKANG'S_WORKSHOP; PROJECT NAME; 형식번호; TITLE DRAWING NO.; FILE NAME 6 Axis Robot; KKW-A00-001; Power; KKW-A20-001; 6_Axis_Robot; Controller STM32F407G-DISC1; GND (P2) PD12 PD13 PD14 PD15; (P2) GND; (P1) GND; HV (HighVolt); GND; VDD GND; Data; V+V- A/L (CAN_L); B/H (CAN_H); DC Servo Motor DYNAMIXEL XL430-W250-T 3 EA; BLDC Servo Motor MG4005-10i v2; 3 EA CAN RX CAN TX; CANL; CANH; CAN Transceiver SN65HVD230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

DC/DC Converter

Logic Level Converter
NER-15966

LV (LowVolt) GND

SCL Voice Recogntion Sensor

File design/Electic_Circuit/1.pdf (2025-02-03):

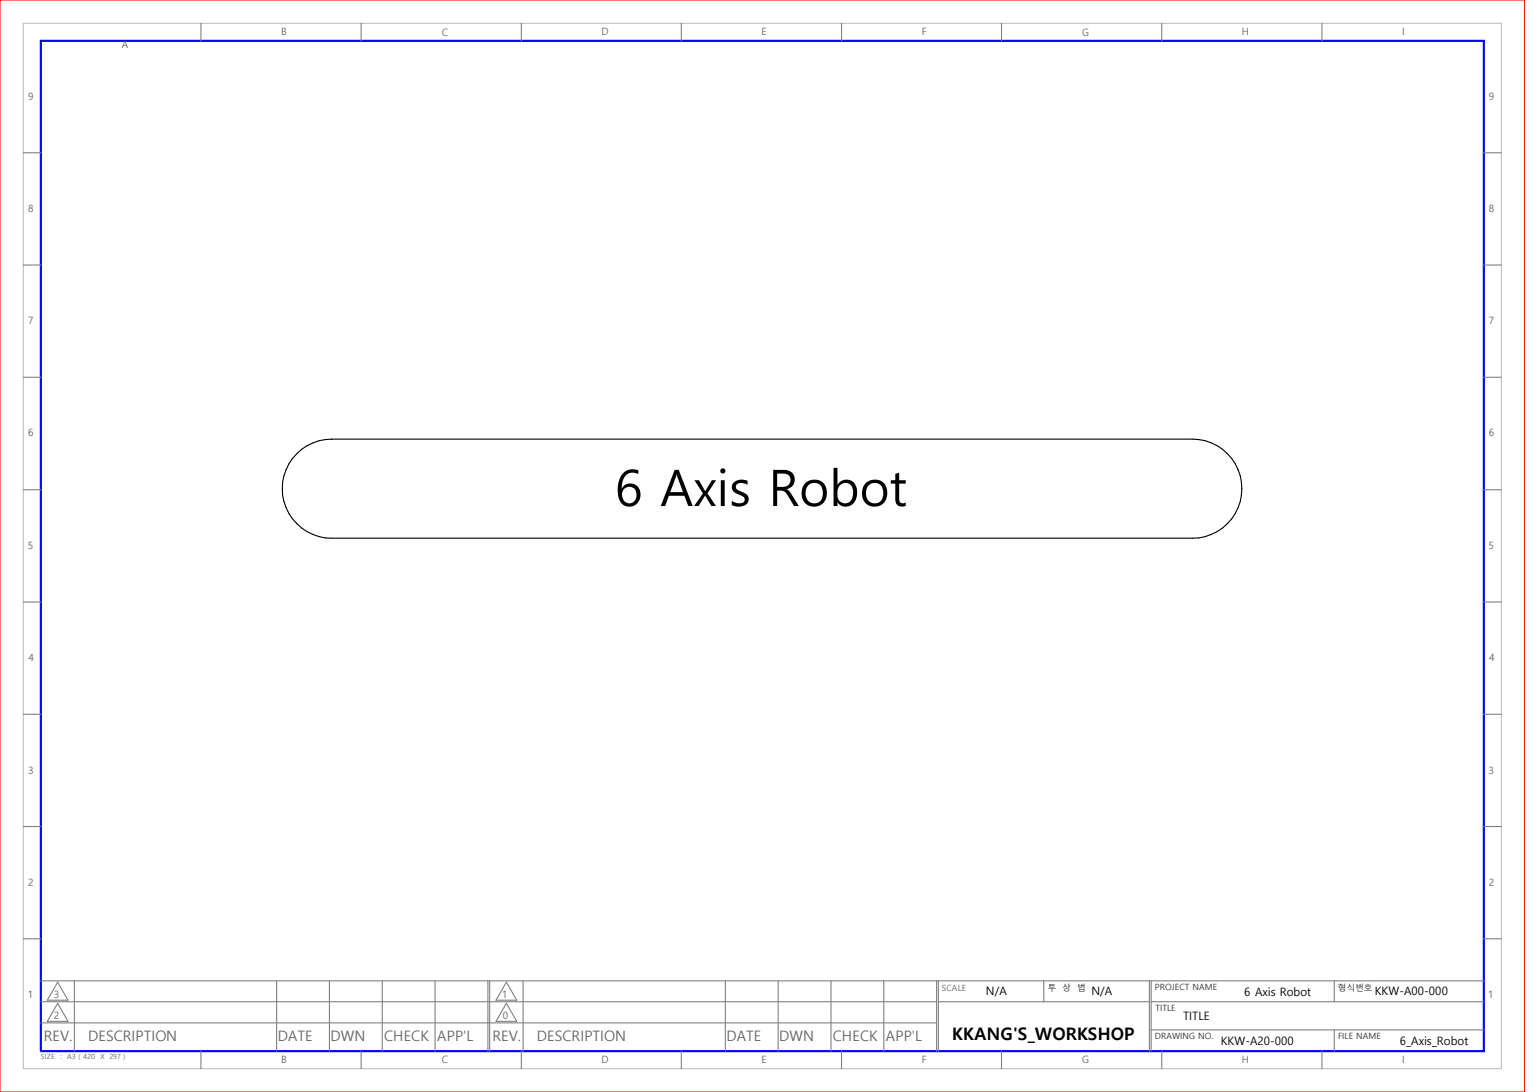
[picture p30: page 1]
SIZE : A3 ( 420 X 297 ); 0 REV.; DESCRIPTION; DATE; DWN; CHECK; APP'L; REV.; SCALE; PROJECT NAME; 형식번호; TITLE DRAWING NO.; FILE NAME 6 Axis Robot; KKW-A00-000; TITLE; KKW-A20-000; 6_Axis_Robot; 6 Axis Robot; KKANG'S_WORKSHOP

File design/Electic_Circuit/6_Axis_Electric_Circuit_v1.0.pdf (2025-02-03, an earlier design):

9

8

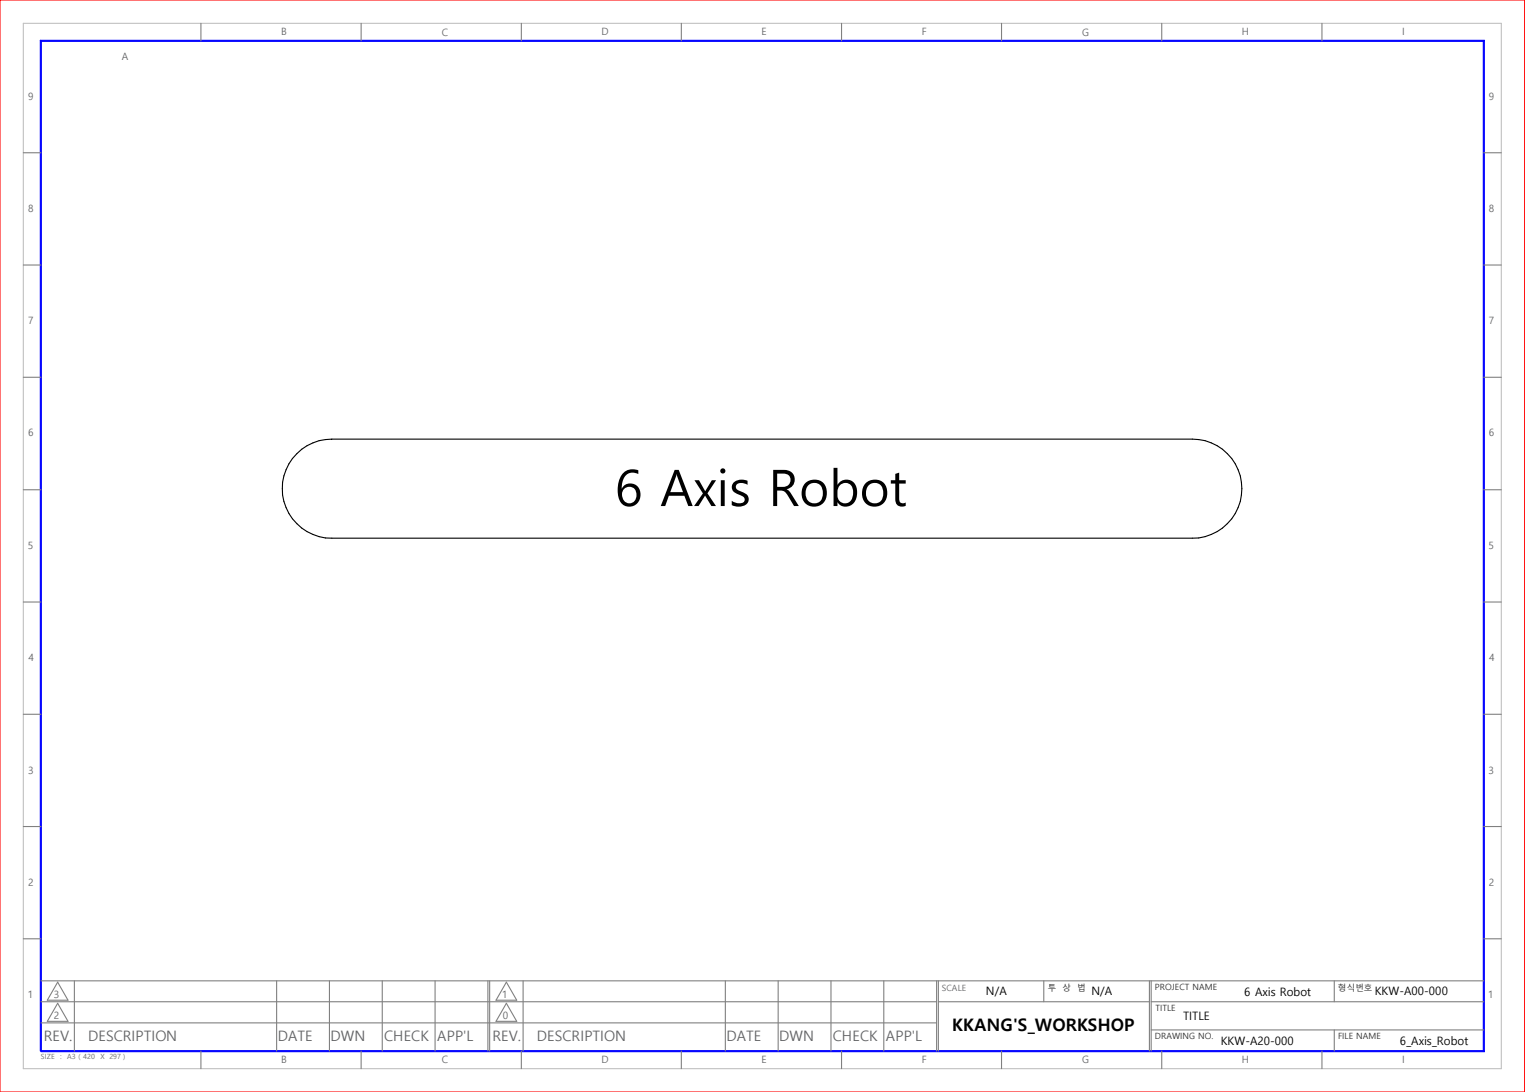
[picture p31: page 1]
SIZE : A3 ( 420 X 297 ); 0 REV.; DESCRIPTION; DATE; DWN; CHECK; APP'L; REV.; SCALE; PROJECT NAME; 형식번호; TITLE DRAWING NO.; FILE NAME 6 Axis Robot; KKW-A00-000; TITLE; KKW-A20-000; 6_Axis_Robot; 6 Axis Robot; KKANG'S_WORKSHOP

9

8

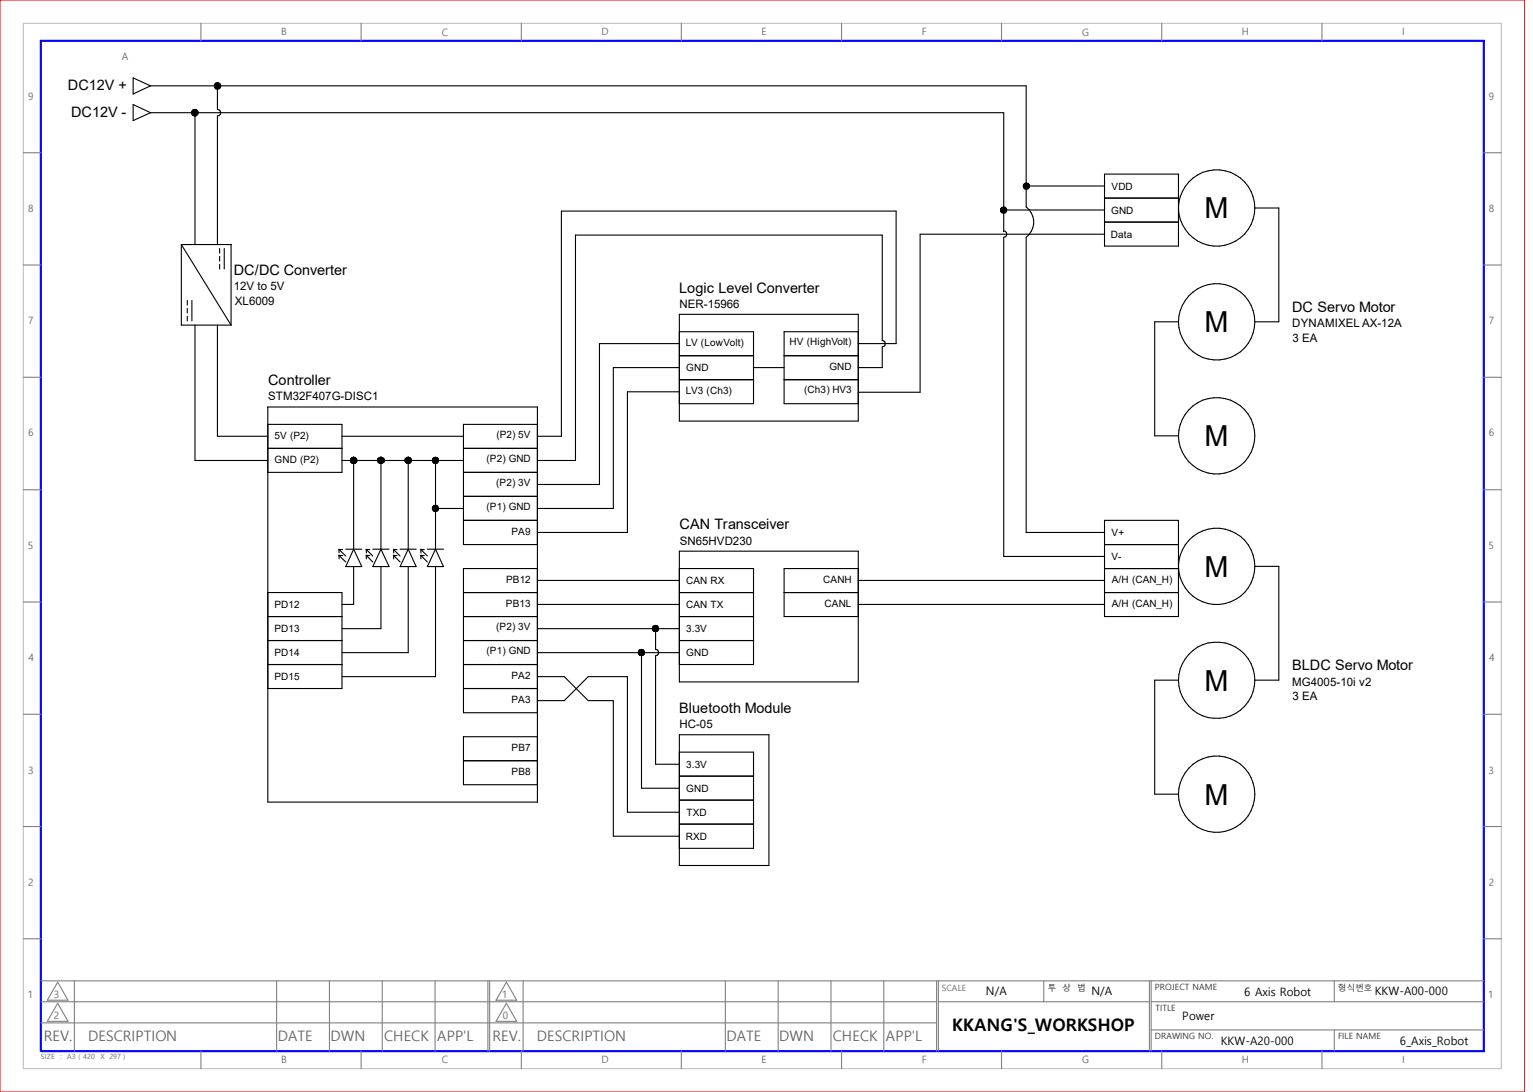
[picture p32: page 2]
SIZE : A3 ( 420 X 297 ); 0 REV.; DESCRIPTION; DATE; DWN; CHECK; APP'L; REV.; SCALE; KKANG'S_WORKSHOP; PROJECT NAME; 형식번호; TITLE DRAWING NO.; FILE NAME 6 Axis Robot; KKW-A00-000; Power; KKW-A20-000; 6_Axis_Robot; Controller STM32F407G-DISC1; GND (P2) PD12 PD13 PD14 PD15; (P2) GND; (P1) GND; HV (HighVolt); GND; VDD GND; Data; V+V- A/H (CAN_H); A/H (CAN_H); DYNAMIXEL AX-12A 3 EA; 3 EA CAN RX CAN TX; CANH; 3.3V GND; TXD; RXD; Bluetooth Module HC-05

DC/DC Converter

Logic Level Converter
NER-15966

DC Servo Motor

LV (LowVolt) GND

CANL CAN Transceiver
SN65HVD230

BLDC Servo Motor

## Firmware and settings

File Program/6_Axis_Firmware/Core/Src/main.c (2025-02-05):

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
/* Includes ------------------------------------------------------------------*/
#include "main.h"
#include "cmsis_os.h"

/* USER CODE BEGIN Includes */
#include <stdio.h>
#include <stdlib.h>
#include <string.h>

#include "at24cxx.h"
#include "df2301q.h"
#include "mg4005.h"
#include "xl430.h"
/* USER CODE END Includes */

/* USER CODE BEGIN PD */
#define ROBOT_INIT_FLAG 0x01
#define ROBOT_INITCOMP_FLAG 0x02
#define ROBOT_STOP_FLAG 0x04
#define ROBOT_STOPCOMP_FLAG 0x08

#define EEPROM_BUSY 0x01

#define MG4005_ID1_INIT 0
#define MG4005_ID2_INIT 0
#define MG4005_ID3_INIT 0
#define MG4005_ID1_OFFSET 180
#define MG4005_SPEED 300

#define XL430_ID4_INIT 17
#define XL430_ID5_INIT 180
#define XL430_ID6_INIT 180
#define XL430_SPEED 218
/* USER CODE END PD */

CAN_HandleTypeDef hcan2;

I2C_HandleTypeDef hi2c1;

UART_HandleTypeDef huart2;
UART_HandleTypeDef huart3;

/* Definitions for defaultTask */
osThreadId_t defaultTaskHandle;
const osThreadAttr_t defaultTask_attributes = {
  .name = "defaultTask",
  .stack_size = 128 * 4,
  .priority = (osPriority_t) osPriorityLow,
};
/* Definitions for Task_VIT */
osThreadId_t Task_VITHandle;
const osThreadAttr_t Task_VIT_attributes = {
  .name = "Task_VIT",
  .stack_size = 128 * 4,
  .priority = (osPriority_t) osPriorityNormal1,
};
/* Definitions for Task_Motor */
osThreadId_t Task_MotorHandle;
const osThreadAttr_t Task_Motor_attributes = {
  .name = "Task_Motor",
  .stack_size = 256 * 4,
  .priority = (osPriority_t) osPriorityNormal2,
};
/* Definitions for Task_Data */
osThreadId_t Task_DataHandle;
const osThreadAttr_t Task_Data_attributes = {
  .name = "Task_Data",
  .stack_size = 128 * 4,
  .priority = (osPriority_t) osPriorityNormal3,
};
/* Definitions for Task_GetCMD */
osThreadId_t Task_GetCMDHandle;
const osThreadAttr_t Task_GetCMD_attributes = {
  .name = "Task_GetCMD",
  .stack_size = 128 * 4,
  .priority = (osPriority_t) osPriorityNormal,
};
/* Definitions for Task_BLE */
osThreadId_t Task_BLEHandle;
const osThreadAttr_t Task_BLE_attributes = {
  .name = "Task_BLE",
  .stack_size = 128 * 4,
  .priority = (osPriority_t) osPriorityNormal4,
};
/* Definitions for ble_IT */
osMessageQueueId_t ble_ITHandle;
const osMessageQueueAttr_t ble_IT_attributes = {
  .name = "ble_IT"
};
/* Definitions for voice_IT */
osMessageQueueId_t voice_ITHandle;
const osMessageQueueAttr_t voice_IT_attributes = {
  .name = "voice_IT"
};
/* Definitions for pos_data */
osMessageQueueId_t pos_dataHandle;
const osMessageQueueAttr_t pos_data_attributes = {
  .name = "pos_data"
};
/* Definitions for voice_data */
osMessageQueueId_t voice_dataHandle;
const osMessageQueueAttr_t voice_data_attributes = {
  .name = "voice_data"
};
/* Definitions for pos_single */
osMessageQueueId_t pos_singleHandle;
const osMessageQueueAttr_t pos_single_attributes = {
  .name = "pos_single"
};
/* Definitions for bSem_BLE */
osSemaphoreId_t bSem_BLEHandle;
const osSemaphoreAttr_t bSem_BLE_attributes = {
  .name = "bSem_BLE"
};
/* Definitions for bSem_Voice */
osSemaphoreId_t bSem_VoiceHandle;
const osSemaphoreAttr_t bSem_Voice_attributes = {
  .name = "bSem_Voice"
};
/* Definitions for cmdFlag */
osEventFlagsId_t cmdFlagHandle;
const osEventFlagsAttr_t cmdFlag_attributes = {
  .name = "cmdFlag"
};
/* Definitions for i2cFlag */
osEventFlagsId_t i2cFlagHandle;
const osEventFlagsAttr_t i2cFlag_attributes = {
  .name = "i2cFlag"
};
/* USER CODE BEGIN PV */
// BLE module code
typedef struct {
	uint8_t cmd[4];
	uint8_t idx;
	uint8_t pos1[4];
	uint8_t pos2[4];
	uint8_t pos3[4];
	uint8_t pos4[4];
	uint8_t pos5[4];
	uint8_t pos6[4];
} bleData;

typedef struct {
	uint8_t idx;
	int32_t pos1;
	int32_t pos2;
	int32_t pos3;
	int32_t pos4;
	int32_t pos5;
	int32_t pos6;
} posData;

typedef struct {
	uint8_t id;
	int16_t pos;
} posSingleData;

bleData *pBle_it;
posData *pPos_data;
uint8_t uart2_rx = 0;

// Voice sensor code
uint8_t *pVoice_it;
uint8_t *pVoice_data;
uint8_t i2c1_rx = 0;

// MG4005 code
CAN_FilterTypeDef canFilter;
CAN_RxHeaderTypeDef canRxHeader;
CAN_TxHeaderTypeDef canTxHeader;
uint8_t canRx0Data[8];
uint32_t canTxMailbox;
uint8_t canTxData[8];

// XL430 code
uint8_t tx_packet[64];

/* USER CODE END PV */

void SystemClock_Config(void);
static void MX_GPIO_Init(void);
static void MX_CAN2_Init(void);
static void MX_USART2_UART_Init(void);
static void MX_I2C1_Init(void);
static void MX_USART3_UART_Init(void);
void StartDefaultTask(void *argument);
void VoiceInterrupt(void *argument);
void Motor(void *argument);
void DataParse(void *argument);
void GetVoiceCmd(void *argument);
void BLEInterrupt(void *argument);

/* USER CODE BEGIN PFP */
void PosSetDataParsing(bleData *p, posData *data);
void posSingleDataParsing(bleData *p, posSingleData *data, uint8_t id);
void PosSaveDataParsing(bleData *p, uint8_t *save_arr);
void PosSaveDataDecode(uint8_t *save_arr, posData *data);
/* USER CODE END PFP */

/* USER CODE BEGIN 0 */
//int _write(int file, char *p, int len) {
//	for (int i = 0; i < len; i++) {
//		ITM_SendChar((*p++));
//	}
//	return len;
//}
/* USER CODE END 0 */

/**
  * @brief  The application entry point.
  * @retval int
  */
int main(void)
{
  /* MCU Configuration--------------------------------------------------------*/

  /* Reset of all peripherals, Initializes the Flash interface and the Systick. */
  HAL_Init();

  /* Configure the system clock */
  SystemClock_Config();

  /* Initialize all configured peripherals */
  MX_GPIO_Init();
  MX_CAN2_Init();
  MX_USART2_UART_Init();
  MX_I2C1_Init();
  MX_USART3_UART_Init();
  /* USER CODE BEGIN 2 */
	// Boot delay
	HAL_Delay(2000);

	HAL_UART_Receive_IT(&huart2, &uart2_rx, 1);
	InitCANFilter();
  /* USER CODE END 2 */

  /* Init scheduler */
  osKernelInitialize();

  /* USER CODE BEGIN RTOS_MUTEX */
	/* add mutexes, ... */
  /* USER CODE END RTOS_MUTEX */

  /* Create the semaphores(s) */
  /* creation of bSem_BLE */
  bSem_BLEHandle = osSemaphoreNew(1, 1, &bSem_BLE_attributes);

  /* creation of bSem_Voice */
  bSem_VoiceHandle = osSemaphoreNew(1, 1, &bSem_Voice_attributes);

  /* USER CODE BEGIN RTOS_SEMAPHORES */
	/* add semaphores, ... */
  /* USER CODE END RTOS_SEMAPHORES */

  /* USER CODE BEGIN RTOS_TIMERS */
	/* start timers, add new ones, ... */
  /* USER CODE END RTOS_TIMERS */

  /* Create the queue(s) */
  /* creation of ble_IT */
  ble_ITHandle = osMessageQueueNew (5, sizeof(bleData), &ble_IT_attributes);

  /* creation of voice_IT */
  voice_ITHandle = osMessageQueueNew (5, sizeof(uint8_t), &voice_IT_attributes);

  /* creation of pos_data */
  pos_dataHandle = osMessageQueueNew (5, sizeof(posData), &pos_data_attributes);

  /* creation of voice_data */
  voice_dataHandle = osMessageQueueNew (5, sizeof(uint8_t), &voice_data_attributes);

  /* creation of pos_single */
  pos_singleHandle = osMessageQueueNew (5, sizeof(posSingleData), &pos_single_attributes);

  /* USER CODE BEGIN RTOS_QUEUES */
	/* add queues, ... */
  /* USER CODE END RTOS_QUEUES */

  /* Create the thread(s) */
  /* creation of defaultTask */
  defaultTaskHandle = osThreadNew(StartDefaultTask, NULL, &defaultTask_attributes);

  /* creation of Task_VIT */
  Task_VITHandle = osThreadNew(VoiceInterrupt, NULL, &Task_VIT_attributes);

  /* creation of Task_Motor */
  Task_MotorHandle = osThreadNew(Motor, NULL, &Task_Motor_attributes);

  /* creation of Task_Data */
  Task_DataHandle = osThreadNew(DataParse, NULL, &Task_Data_attributes);

  /* creation of Task_GetCMD */
  Task_GetCMDHandle = osThreadNew(GetVoiceCmd, NULL, &Task_GetCMD_attributes);

  /* creation of Task_BLE */
  Task_BLEHandle = osThreadNew(BLEInterrupt, NULL, &Task_BLE_attributes);

  /* USER CODE BEGIN RTOS_THREADS */
	/* add threads, ... */
  /* USER CODE END RTOS_THREADS */

  /* Create the event(s) */
  /* creation of cmdFlag */
  cmdFlagHandle = osEventFlagsNew(&cmdFlag_attributes);

  /* creation of i2cFlag */
  i2cFlagHandle = osEventFlagsNew(&i2cFlag_attributes);

  /* USER CODE BEGIN RTOS_EVENTS */
	/* add events, ... */
	osEventFlagsSet(cmdFlagHandle, ROBOT_INIT_FLAG);
  /* USER CODE END RTOS_EVENTS */

  /* Start scheduler */
  osKernelStart();

  /* We should never get here as control is now taken by the scheduler */
  /* Infinite loop */
  /* USER CODE BEGIN WHILE */
	while (1) {
    /* USER CODE END WHILE */

    /* USER CODE BEGIN 3 */
	}
  /* USER CODE END 3 */
}

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
/* USER CODE BEGIN 4 */
// Bluetooth data Receive
void HAL_UART_RxCpltCallback(UART_HandleTypeDef *huart) {
	if (huart->Instance == USART2) {
		osSemaphoreRelease(bSem_BLEHandle);
	}
}

void HAL_I2C_MemRxCpltCallback(I2C_HandleTypeDef *hi2c) {
	if (hi2c->Instance == I2C1) {
		osSemaphoreRelease(bSem_VoiceHandle);
	}
}

void PosSetDataParsing(bleData *p, posData *data) {
	data->pos1 = (int32_t) (strtoul(p->pos1, NULL, 10) - MG4005_ID1_OFFSET);
	data->pos2 = (int32_t) strtoul(p->pos2, NULL, 10);
	data->pos3 = (int32_t) strtoul(p->pos3, NULL, 10);
	data->pos4 = (int32_t) strtoul(p->pos4, NULL, 10);
	data->pos5 = (int32_t) strtoul(p->pos5, NULL, 10);
	data->pos6 = (int32_t) strtoul(p->pos6, NULL, 10);
}

void posSingleDataParsing(bleData *p, posSingleData *data, uint8_t id) {
	data->id = id;
	data->pos = (int16_t) strtoul(p->pos1, NULL, 10);
}

void PosSaveDataParsing(bleData *p, uint8_t *save_arr) {

	int16_t pos1 = (int16_t) strtoul(p->pos1, NULL, 10);
	int16_t pos2 = (int16_t) strtoul(p->pos2, NULL, 10);
	int16_t pos3 = (int16_t) strtoul(p->pos3, NULL, 10);
	int16_t pos4 = (int16_t) strtoul(p->pos4, NULL, 10);
	int16_t pos5 = (int16_t) strtoul(p->pos5, NULL, 10);
	int16_t pos6 = (int16_t) strtoul(p->pos6, NULL, 10);

	save_arr[0] = *((uint8_t*) (&pos1));
	save_arr[1] = *((uint8_t*) (&pos1) + 1);
	save_arr[2] = *((uint8_t*) (&pos2));
	save_arr[3] = *((uint8_t*) (&pos2) + 1);
	save_arr[4] = *((uint8_t*) (&pos3));
	save_arr[5] = *((uint8_t*) (&pos3) + 1);
	save_arr[6] = *((uint8_t*) (&pos4));
	save_arr[7] = *((uint8_t*) (&pos4) + 1);
	save_arr[8] = *((uint8_t*) (&pos5));
	save_arr[9] = *((uint8_t*) (&pos5) + 1);
	save_arr[10] = *((uint8_t*) (&pos6));
	save_arr[11] = *((uint8_t*) (&pos6) + 1);

	printf("idx: %d\r\n", p->idx - 48);
	printf("pos2: %d\r\n", pos2);
	printf("SaveArr2: 0x%x, 0x%x\r\n", save_arr[2], save_arr[3]);
}

void PosSaveDataDecode(uint8_t *save_arr, posData *data) {
	data->pos1 = ((int32_t) (((uint16_t) save_arr[1] << 8)
			| (uint16_t) save_arr[0])) - MG4005_ID1_OFFSET;
	data->pos2 = (int32_t) (((uint16_t) save_arr[3] << 8)
			| (uint16_t) save_arr[2]);
	data->pos3 = (int32_t) (((uint16_t) save_arr[5] << 8)
			| (uint16_t) save_arr[4]);
	data->pos4 = (int32_t) (((uint16_t) save_arr[7] << 8)
			| (uint16_t) save_arr[6]);
	data->pos5 = (int32_t) (((uint16_t) save_arr[9] << 8)
			| (uint16_t) save_arr[8]);
	data->pos6 = (int32_t) (((uint16_t) save_arr[11] << 8)
			| (uint16_t) save_arr[10]);

	printf("Decode SaveArr2: 0x%x, 0x%x\r\n", save_arr[2], save_arr[3]);
	printf("Decode pos2: %d", data->pos2);
}
/* USER CODE END 4 */

/* USER CODE BEGIN Header_StartDefaultTask */
/**
 * @brief  Function implementing the defaultTask thread.
 * @param  argument: Not used
 * @retval None
 */
/* USER CODE END Header_StartDefaultTask */
void StartDefaultTask(void *argument)
{
  /* USER CODE BEGIN 5 */
	/* Infinite loop */
	for (;;) {
		osDelay(1);
	}
  /* USER CODE END 5 */
}

/* USER CODE BEGIN Header_VoiceInterrupt */
/**
 * @brief Function implementing the Task_VIT thread.
 * @param argument: Not used
 * @retval None
 */
/* USER CODE END Header_VoiceInterrupt */
void VoiceInterrupt(void *argument)
{
  /* USER CODE BEGIN VoiceInterrupt */
	uint8_t voice_cmd = 0;
	/* Infinite loop */
	for (;;) {
		if (bSem_VoiceHandle != NULL) {
			if (osSemaphoreAcquire(bSem_VoiceHandle, osWaitForever) == osOK) {
				HAL_GPIO_WritePin(GPIOD, GPIO_PIN_12, SET);

				if (i2c1_rx != 0) {
					voice_cmd = i2c1_rx;
					osMessageQueuePut(voice_ITHandle, &voice_cmd, 1U, 0U);

					HAL_GPIO_WritePin(GPIOD, GPIO_PIN_12, RESET);
				}
			}
		}
//		osDelay(1);
	}
  /* USER CODE END VoiceInterrupt */
}

/* USER CODE BEGIN Header_Motor */
/**
 * @brief Function implementing the Task_Motor thread.
 * @param argument: Not used
 * @retval None
 */
/* USER CODE END Header_Motor */
void Motor(void *argument)
{
  /* USER CODE BEGIN Motor */
	osStatus_t pos_data_event;
	osStatus_t pos_single_event;
	osStatus_t voice_data_event;

	posData pos_data;
	posSingleData single_data;
	uint8_t voice_data;
	uint32_t event_flags;

	posData decode_data;
	uint8_t addr = 0x00;
	uint8_t eeprom_data[12] = { 0x00 };

	/* Infinite loop */
	for (;;) {
		pos_data_event = osMessageQueueGet(pos_dataHandle, &pos_data, 2U, 10);
		pos_single_event = osMessageQueueGet(pos_singleHandle, &single_data, 2U,
				10);
		voice_data_event = osMessageQueueGet(voice_dataHandle, &voice_data, 3U,
				10);

		event_flags = osEventFlagsGet(cmdFlagHandle);

		if ((event_flags & ROBOT_INIT_FLAG)
				&& !(event_flags & ROBOT_INITCOMP_FLAG)) {
			// Robot initialize for motor zero position
			printf("Robot initialize\r\n");

			// Motor ON
//			MG4005On(0x01);
//			MG4005On(0x02);
//			MG4005On(0x03);

			xl430TorqueEnable(0x04, TORQUE_MODE_ON);
			xl430TorqueEnable(0x05, TORQUE_MODE_ON);
			xl430TorqueEnable(0x06, TORQUE_MODE_ON);

			xl430ProfVelo(0x04, XL430_SPEED);
			xl430ProfVelo(0x05, XL430_SPEED);
			xl430ProfVelo(0x06, XL430_SPEED);

			// Motor zero position init
			MG4005MultiLoop2(0x01, MG4005_SPEED, MG4005_ID1_INIT);
			MG4005MultiLoop2(0x02, MG4005_SPEED, MG4005_ID2_INIT);
			MG4005MultiLoop2(0x03, MG4005_SPEED, MG4005_ID3_INIT);

			xl430GoalPos(0x04, XL430_ID4_INIT);
			xl430GoalPos(0x05, XL430_ID5_INIT);
			xl430GoalPos(0x06, XL430_ID6_INIT);

			osEventFlagsSet(cmdFlagHandle, ROBOT_INITCOMP_FLAG);
			osEventFlagsClear(cmdFlagHandle, ROBOT_INIT_FLAG);
		}

		if ((event_flags & ROBOT_STOP_FLAG)
				&& !(event_flags & ROBOT_STOPCOMP_FLAG)) {
			// Robot motor stop
			printf("Robot stop\r\n");

			osEventFlagsSet(cmdFlagHandle, ROBOT_STOPCOMP_FLAG);
			osEventFlagsClear(cmdFlagHandle, ROBOT_STOP_FLAG);
		}

		if (pos_data_event == osOK) {
			// Robot motor commend
			printf("Robot set motor: %d. %d. %d. %d. %d. %d\r\n", pos_data.pos1,
					pos_data.pos2, pos_data.pos3, pos_data.pos4, pos_data.pos5,
					pos_data.pos6);

			// Motor angle set
			MG4005MultiLoop2(0x01, MG4005_SPEED, (int) pos_data.pos1);
			MG4005MultiLoop2(0x02, MG4005_SPEED, (int) pos_data.pos2);
			MG4005MultiLoop2(0x03, MG4005_SPEED, (int) pos_data.pos3);

			xl430GoalPos(0x04, (uint32_t) pos_data.pos4);
			xl430GoalPos(0x05, (uint32_t) pos_data.pos5);
			xl430GoalPos(0x06, (uint32_t) pos_data.pos6);
		}

		if (pos_single_event == osOK) {
			// Robot realtime motor commend
			printf("Robot S: 0x%02x, %d\r\n", single_data.id, single_data.pos);

			switch (single_data.id) {
			case 0x01:
				MG4005MultiLoop2(0x01, MG4005_SPEED,
						(int16_t) (single_data.pos - MG4005_ID1_OFFSET));
				break;
			case 0x02:
				MG4005MultiLoop2(0x02, MG4005_SPEED, (int) single_data.pos);
				break;
			case 0x03:
				MG4005MultiLoop2(0x03, MG4005_SPEED, (int) single_data.pos);
				break;
			case 0x04:
				xl430GoalPos(0x04, (uint32_t) single_data.pos);
				break;
			case 0x05:
				xl430GoalPos(0x05, (uint32_t) single_data.pos);
				break;
			case 0x06:
				xl430GoalPos(0x06, (uint32_t) single_data.pos);
				break;
			}
		}

		if (voice_data_event == osOK) {
			// Voice commend
			printf("Voice input: %02x\r\n", voice_data);

			switch (voice_data) {
			case 0x05:
			case 0x06:
			case 0x07:
			case 0x08:
			case 0x09:
				// Read save data (EEPROM)
				addr = (voice_data - 0x05) * 12;

				AT24Read(addr, eeprom_data, 12);
				PosSaveDataDecode(eeprom_data, &decode_data);

				// Motor angle set
				MG4005MultiLoop2(0x01, MG4005_SPEED,
						(int32_t) decode_data.pos1);
				MG4005MultiLoop2(0x02, MG4005_SPEED,
						(int32_t) decode_data.pos2);
				MG4005MultiLoop2(0x03, MG4005_SPEED,
						(int32_t) decode_data.pos3);

				xl430GoalPos(0x04, (uint32_t) decode_data.pos4);
				xl430GoalPos(0x05, (uint32_t) decode_data.pos5);
				xl430GoalPos(0x06, (uint32_t) decode_data.pos6);
				break;
			case 0x0A:
				// Guidance voice ON
				DF2301QSetMuteMode(DF2301Q_MUTE_OFF);
				break;
			case 0x0B:
				// Guidance voice OFF
				DF2301QSetMuteMode(DF2301Q_MUTE_ON);
				break;
			case 0x17:
				// Test code
				addr = 0x00;

				AT24Read(addr, eeprom_data, 12);
				PosSaveDataDecode(eeprom_data, &decode_data);

				printf("Robot set motor: %d. %d. %d. %d. %d. %d\r\n",
						decode_data.pos1, decode_data.pos2, decode_data.pos3,
						decode_data.pos4, decode_data.pos5, decode_data.pos6);

				// Motor angle set
				MG4005MultiLoop2(0x01, MG4005_SPEED,
						(int32_t) decode_data.pos1);
				MG4005MultiLoop2(0x02, MG4005_SPEED,
						(int32_t) decode_data.pos2);
				MG4005MultiLoop2(0x03, MG4005_SPEED,
						(int32_t) decode_data.pos3);

				xl430GoalPos(0x04, (uint32_t) decode_data.pos4);
				xl430GoalPos(0x05, (uint32_t) decode_data.pos5);
				xl430GoalPos(0x06, (uint32_t) decode_data.pos6);
				break;
			case 0x52:
				// Reset
				osEventFlagsSet(cmdFlagHandle, ROBOT_INIT_FLAG);

				osEventFlagsClear(cmdFlagHandle, ROBOT_INITCOMP_FLAG);
				osEventFlagsClear(cmdFlagHandle, ROBOT_STOPCOMP_FLAG);
				break;
			}
		}

		osDelay(1);
	}
  /* USER CODE END Motor */
}

/* USER CODE BEGIN Header_DataParse */
/**
 * @brief Function implementing the Task_Data thread.
 * @param argument: Not used
 * @retval None
 */
/* USER CODE END Header_DataParse */
void DataParse(void *argument)
{
  /* USER CODE BEGIN DataParse */
	osStatus_t ble_it_event;
	osStatus_t voice_it_event;

	bleData ble_it;
	posData parse_data;
	posSingleData single_parse_data;
	uint8_t voice_it;

	/* Infinite loop */
	for (;;) {
		ble_it_event = osMessageQueueGet(ble_ITHandle, &ble_it, 0U, 10);
		voice_it_event = osMessageQueueGet(voice_ITHandle, &voice_it, 1U, 10);

		if (ble_it_event == osOK) {
			HAL_GPIO_WritePin(GPIOD, GPIO_PIN_13, SET);

			printf("%s\r\n", ble_it.cmd);
			if (ble_it.cmd[0] == 'P') {
				switch (ble_it.cmd[1]) {
				case '1':
					osEventFlagsClear(cmdFlagHandle, ROBOT_INITCOMP_FLAG);
					osEventFlagsClear(cmdFlagHandle, ROBOT_STOPCOMP_FLAG);

					posSingleDataParsing(&ble_it, &single_parse_data, 0x01);
					osMessageQueuePut(pos_singleHandle, &single_parse_data, 2U,
							0U);
					break;
				case '2':
					osEventFlagsClear(cmdFlagHandle, ROBOT_INITCOMP_FLAG);
					osEventFlagsClear(cmdFlagHandle, ROBOT_STOPCOMP_FLAG);

					posSingleDataParsing(&ble_it, &single_parse_data, 0x02);
					osMessageQueuePut(pos_singleHandle, &single_parse_data, 2U,
							0U);
					break;
				case '3':
					osEventFlagsClear(cmdFlagHandle, ROBOT_INITCOMP_FLAG);
					osEventFlagsClear(cmdFlagHandle, ROBOT_STOPCOMP_FLAG);

					posSingleDataParsing(&ble_it, &single_parse_data, 0x03);
					osMessageQueuePut(pos_singleHandle, &single_parse_data, 2U,
							0U);
					break;
				case '4':
					osEventFlagsClear(cmdFlagHandle, ROBOT_INITCOMP_FLAG);
					osEventFlagsClear(cmdFlagHandle, ROBOT_STOPCOMP_FLAG);

					posSingleDataParsing(&ble_it, &single_parse_data, 0x04);
					osMessageQueuePut(pos_singleHandle, &single_parse_data, 2U,
							0U);
					break;
				case '5':
					osEventFlagsClear(cmdFlagHandle, ROBOT_INITCOMP_FLAG);
					osEventFlagsClear(cmdFlagHandle, ROBOT_STOPCOMP_FLAG);

					posSingleDataParsing(&ble_it, &single_parse_data, 0x05);
					osMessageQueuePut(pos_singleHandle, &single_parse_data, 2U,
							0U);
					break;
				case '6':
					osEventFlagsClear(cmdFlagHandle, ROBOT_INITCOMP_FLAG);
					osEventFlagsClear(cmdFlagHandle, ROBOT_STOPCOMP_FLAG);

					posSingleDataParsing(&ble_it, &single_parse_data, 0x06);
					osMessageQueuePut(pos_singleHandle, &single_parse_data, 2U,
							0U);
					break;
				}
			} else if (!(strcmp(ble_it.cmd, "STOP"))) {
				// stop flag on
				osEventFlagsSet(cmdFlagHandle, ROBOT_STOP_FLAG);
				osEventFlagsClear(cmdFlagHandle, ROBOT_INITCOMP_FLAG);
				osEventFlagsClear(cmdFlagHandle, ROBOT_STOPCOMP_FLAG);

			} else if (!(strcmp(ble_it.cmd, "SET"))) {
				// stop flag off & put pos data
				osEventFlagsClear(cmdFlagHandle, ROBOT_INITCOMP_FLAG);
				osEventFlagsClear(cmdFlagHandle, ROBOT_STOPCOMP_FLAG);

				PosSetDataParsing(&ble_it, &parse_data);
				osMessageQueuePut(pos_dataHandle, &parse_data, 2U, 0U);

			} else if (!(strcmp(ble_it.cmd, "SAV"))) {
				// eeprom write
				uint8_t parse_idx = ble_it.idx - 48;
				uint8_t addr = parse_idx * 12;
				uint8_t data[12] = {0x00};

				PosSaveDataParsing(&ble_it, data);
				AT24Write(addr, data, 12);

			} else if (!(strcmp(ble_it.cmd, "DEL"))) {
				// eeprom delete
				uint8_t parse_idx = ble_it.idx - 48;
				uint8_t addr;
				uint8_t next_addr;
				uint8_t data[12] = {0x00};

				for (int i = parse_idx; i < 4; i++) {
					addr = i * 12;
					next_addr = addr + 12;

					AT24Read(next_addr, data, 12);

					AT24Write(addr, data, 12);
				}

				memset(data, 0x00, 12);
				addr = 0x30; // 5th address
				AT24Write(addr, data, 12);

			} else if (!(strcmp(ble_it.cmd, "RSET"))) {
				// connect or reset flag on
				osEventFlagsSet(cmdFlagHandle, ROBOT_INIT_FLAG);

				osEventFlagsClear(cmdFlagHandle, ROBOT_INITCOMP_FLAG);
				osEventFlagsClear(cmdFlagHandle, ROBOT_STOPCOMP_FLAG);

			}

			HAL_GPIO_WritePin(GPIOD, GPIO_PIN_13, RESET);
		}

		if (voice_it_event == osOK) {
			HAL_GPIO_WritePin(GPIOD, GPIO_PIN_14, SET);

			osEventFlagsClear(cmdFlagHandle, ROBOT_INIT_FLAG);
			osEventFlagsClear(cmdFlagHandle, ROBOT_INITCOMP_FLAG);
			osEventFlagsClear(cmdFlagHandle, ROBOT_STOP_FLAG);
			osEventFlagsClear(cmdFlagHandle, ROBOT_STOPCOMP_FLAG);

			osMessageQueuePut(voice_dataHandle, &voice_it, 3U, 0U);
			HAL_GPIO_WritePin(GPIOD, GPIO_PIN_14, RESET);
		}
		osDelay(1);
	}
  /* USER CODE END DataParse */
}
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

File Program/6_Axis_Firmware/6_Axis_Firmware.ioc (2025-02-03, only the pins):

Mcu.UserName=STM32F407VETx
PA2.GPIO_Label=USART2_TX(HC-05)
PA2.Signal=USART2_TX
PA3.GPIO_Label=USART2_RX(HC-05)
PA3.Signal=USART2_RX
PB10.GPIO_Label=USART3_TX (XL430-W250-T)
PB10.Signal=USART3_TX
PB12.Signal=CAN2_RX
PB13.Signal=CAN2_TX
PB7.GPIO_Label=I2C1_SDA(Voice recognition sensor)
PB7.Signal=I2C1_SDA
PB8.GPIO_Label=I2C1_SCL(Voice recognition sensor)
PB8.Signal=I2C1_SCL
PD12.GPIO_Label=Green LED
PD12.Signal=GPIO_Output
PD13.GPIO_Label=Orange LED
PD13.Signal=GPIO_Output
PD14.GPIO_Label=Red LED
PD14.Signal=GPIO_Output
PD15.GPIO_Label=Blue LED
PD15.Signal=GPIO_Output
PH0-OSC_IN.Signal=RCC_OSC_IN
PH1-OSC_OUT.Signal=RCC_OSC_OUT

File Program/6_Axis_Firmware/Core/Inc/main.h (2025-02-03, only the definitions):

#define USART2_TX_Pin GPIO_PIN_2
#define USART2_TX_GPIO_Port GPIOA
#define USART2_RX_Pin GPIO_PIN_3
#define USART2_RX_GPIO_Port GPIOA
#define USART3_TX_Pin GPIO_PIN_10
#define USART3_TX_GPIO_Port GPIOB
#define Green_LED_Pin GPIO_PIN_12
#define Green_LED_GPIO_Port GPIOD
#define Orange_LED_Pin GPIO_PIN_13
#define Orange_LED_GPIO_Port GPIOD
#define Red_LED_Pin GPIO_PIN_14
#define Red_LED_GPIO_Port GPIOD
#define Blue_LED_Pin GPIO_PIN_15
#define Blue_LED_GPIO_Port GPIOD
#define I2C1_SDA_Pin GPIO_PIN_7
#define I2C1_SDA_GPIO_Port GPIOB
#define I2C1_SCL_Pin GPIO_PIN_8
#define I2C1_SCL_GPIO_Port GPIOB

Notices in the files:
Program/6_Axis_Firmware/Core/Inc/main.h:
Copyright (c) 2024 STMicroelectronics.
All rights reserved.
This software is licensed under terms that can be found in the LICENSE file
